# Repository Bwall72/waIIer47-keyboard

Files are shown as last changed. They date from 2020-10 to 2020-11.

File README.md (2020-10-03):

# WaIIer47 Mechanical Keyboard
Custom design 47 key ortholinear keyboard with PCB, and Atmega32u4 Microcontroller

## Images

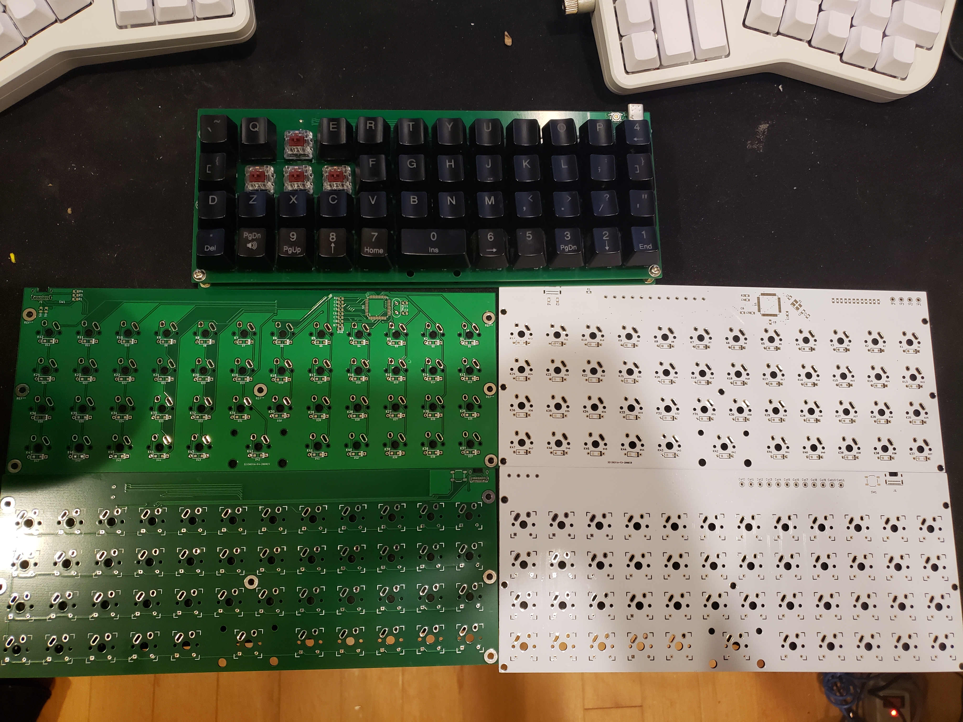
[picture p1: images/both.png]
Both Keyboards

Revision 2 Green, Revision 1 White, Back top, Front bottom

Revision 2
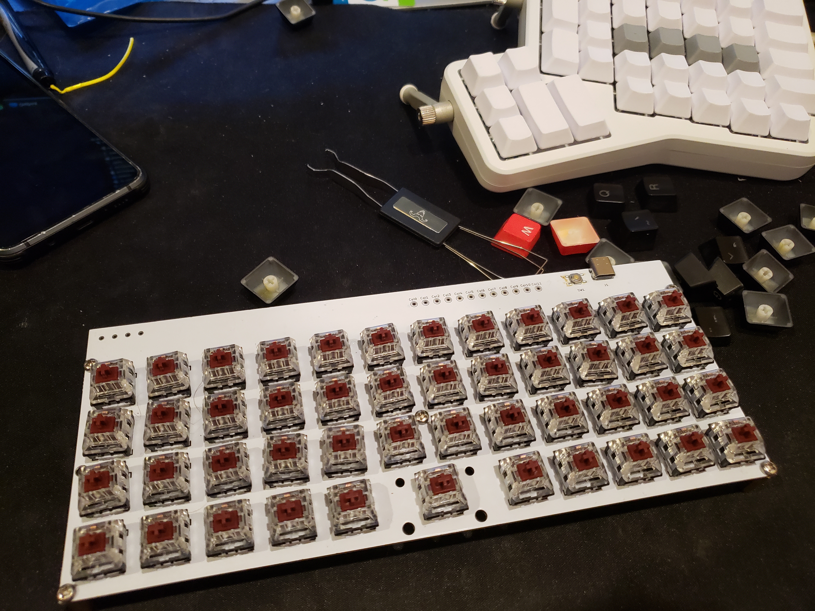
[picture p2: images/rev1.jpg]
Revision 1


# Bill Of Materials

* See [BOM.md](./BOM.md)
* The total cost for a Rev 2 PCB keybarod is:

| Component | Unit Price | Units | Total |
| --- | --- | ----- | ----- |
| Capacitor 22 pF | \$0.043  | 2 | \$0.086  |
| Capacitor 0.1 $\mu$F | \$0.0216  | 5 | \$0.108  |
| Capacitor 1.0 $\mu$F | \$0.055 | 1 | \$0.055 |
| Diode | \$.02446 | 47 | \$1.223 |
| LED | \$0.159 | 1 | \$0.159 |
| USB-C Receptacle | \$1.37 | 1 | \$1.37 |
| Kalih Speed Copper Key Switch | \$0.538 | 47 | \$25.286 |
| Resistor 10 k$\Omega$ | \$0.0071 | 2 | \$0.0142 |
| Resistor 22 $\Omega$ | \$0.0071 | 2 | \$0.0142 |
| Resistor 5.1 k$\Omega$ | \$0.0071 | 2 | \$0.0142 |
| Resistor 220 $\Omega$ | \$0.0071 | 1 | \$0.0071 |
| Push Button Switch | \$0.59 | 1 | \$0.59 |
| Atmega32U4 | \$4.08 | 1 | \$4.08 |
| Crystal Oscillator | \$0.36 | 1 | \$0.36 |
| PCB | \$2.08 | 2 | \$2.08 |
| M3 Screws | \$0.033 | 7 | \$0.233
| M3 Standoff | \$0.033 | 7 | \$0.233
| Total ||| \$35.89

>Notes
>
>* Shipping costs are excluded from the BOM
>* Currently, I am reusing keycaps, so those are not included in the BOM
>  * I am part of the group buy for [KAT Mizu Keycaps](https://old.reddit.com/r/mechmarket/comments/i6aaga/ic_kat_mizu_coming_september_1st/), which would add \$64.44 to the total
>* Kailh Speed Copper are my favorite switches, but they cannot be recomended for this keyboard. They are missing the pins to be used in a plateless keyboard like this one.

# PCB Tutorial
Designing a custom mechanical keyboard PCB using KiCad. The following was based on [Ruiqi Mao's Tutorial](https://github.com/ruiqimao/keyboard-pcb-guide)

## Download Kicad and Install the Mechanical Keyboard Libraries

* Download and install Kicad from https://kicad-pcb.org/
  * During installation, choose to download Kicad's default libraries
* Clone the following two repositories (or download zip and extract):
  * `keyboard_parts.pretty` from https://github.com/tmk/keyboard_parts.pretty
  * `keebs.pretty` from https://github.com/egladman/keebs.pretty
  * `Type-C.pretty` from https://github.com/ai03-2725/Type-C.pretty
  * `kicad_lib_tmk`.lib https://github.com/tmk/kicad_lib_tmk

  Kicad Libraries

* Open `Kicad` > `Preferences` > `Manage Footprint Libraries`
  * In the `Global Libraries` tab, press the folder icon to `Add existing library to table`
  * Navigate to where you cloned the the libraries, click on the `keebs.pretty` and press `OK`
    * Do the same for `keyboard_parts.pretty` and `Type-C.pretty`
  * If done successfully, you should see the following in the `Global Libraries` tab:

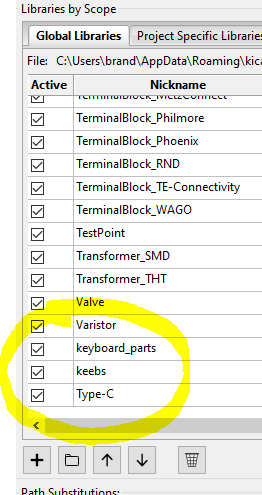
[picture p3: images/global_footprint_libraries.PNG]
Global Footprint Libraries
  
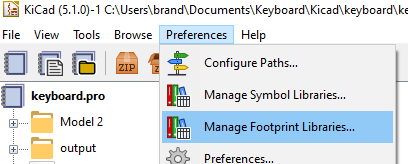
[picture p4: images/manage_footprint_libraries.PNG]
Manage Footprint Libraries
  

* Back in the Kicad Menu, `Preferences` > `Mange Symbol Libraries`
  * In the `Global Libraries` tab, press the folder icon to `Add existing library to table`
  * Navigate to where you cloned `kicad_lib_tmk` and select `keyboard_parts.lib`
  * Navigate to `Type-C.pretty` and select `Type-C.lib`
  * If done successfully, you should see the following:

  Global Symbol Libraries

## Creating The Schematic File

* In Kicad: `file` > `New` > `New Project`
  * Create a new Folder for the project, and give a name for the project (I am using `tutorial_keyboard`)
  * Press `Save`
  * On the left side, you should now see 3 files:
    * `tutorial_keyboard.kicad_pcb`: The PCB file
    * `tutorial_keyboard.pro`: The project file, we will not be using this
    * `tutorial_keyboard.sch`: The schematic file

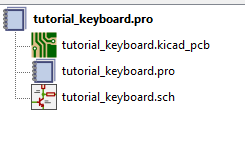
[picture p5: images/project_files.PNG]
Project Files
  

* Click on the `Schematic Layout Editor` button
* Because this schematic will be large, increase the paper size by going to `file` > `Page Settings...` then selecting the `C` page size

## Placing Components on the Schematic

* To place a part, press the `Place symbol` button on the right side
* For the microcontroller:
  * `Place symbol` and click on the page > expand `keybord_parts` > select `ATMEGA32U4` > press `OK` > Click on the sheet to place the component
  * You should now see the component placed on your page with the label U?
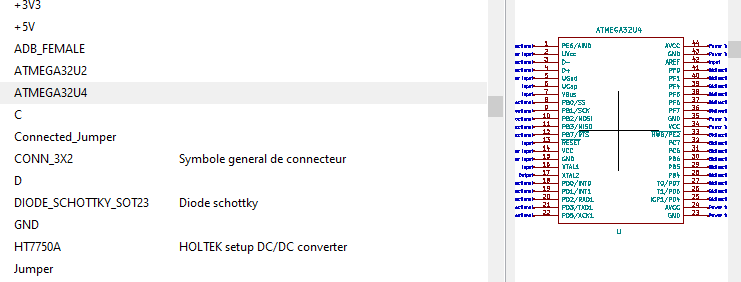
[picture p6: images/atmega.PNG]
Atmega Symbol
  
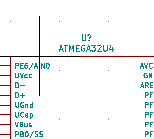
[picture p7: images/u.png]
U?
  
* Place the following components as required by the [datasheet](http://ww1.microchip.com/downloads/en/devicedoc/atmel-7766-8-bit-avr-atmega16u4-32u4_datasheet.pdf)
  * A 10 k$\Omega$ resustor near `HWB/PE2`
    * `Place symbol` > `keyboard_parts` > `R` > `Ok`
      * Press `r` before placing the component, or while hovering over the component after placing to rotate it
      * Hover over it and press `e` to `Edit Value Field`
      * Change the `Text` field to say `10k`
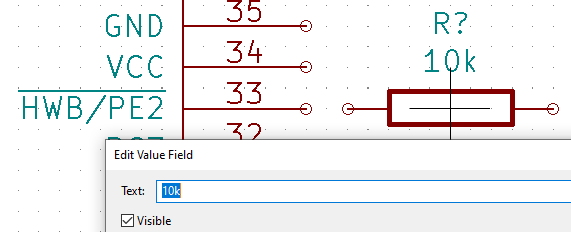
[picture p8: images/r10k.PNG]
R10k
    
  * A 1 $\mu$F capacitor on `UCap`
    * `place symbol` > `keyboard_parts` > `C` > `Ok`
    * Change the its value to `1uF`
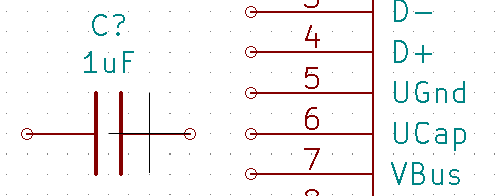
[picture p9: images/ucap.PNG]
UCap
    
    UCap datasheet
* Connect `Vcc` and `GND`
  * On the right side, slect `Place power port` > click on the page
  * Expand the `power` library and select > `VCC` > `Ok`
  * Place the VCC flag near `AVCC`
    * On the right, click the `Place wire` icon
    * Click at the empty circle on `AVCC` and make a connection to the `VCC` flag
    AVCC Connection
    * Repeat for:
      | Pin | Name   |
      |-----|--------|
      | 2   | `UVcc` |
      | 7   | `VBus` |
      | 14  | `VCC`  |
      | 24  | `AVcc` |
      | 34  | `VCC`  |
      | 44  | `AVcc` |
    * Make sure there are 6 total connections to `VCC`
    * Individual connections to `VCC` in the schematic do not need to be connected together
    * Connect `VCC` to a power flag
      * `Place symbol` > Search for `PWR_FLAG` > `PWR_FLAG`
      * Connect the `PWR_FLAG` to `VCC`
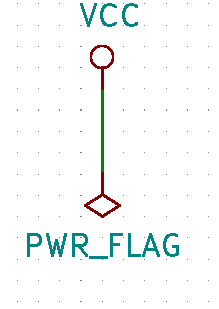
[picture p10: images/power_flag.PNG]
Power Flag
      
  * `Place power port` > `GND` (`Power flag, ground` from the `s`power` library)
    * Create a connection to `GND` on the following pins:
      | Pin | Name   |
      | --- | ------ |
      | 5   | `UGND` |
      | 15  | `GND`  |
      | 23  | `GND`  |
      | 35  | `GND`  |
      | 43  | `GND`  |
    * Additionally, connect the other end of the capacitor and resistor to `GND`
    * Make sure there are 5 connections to `GND`
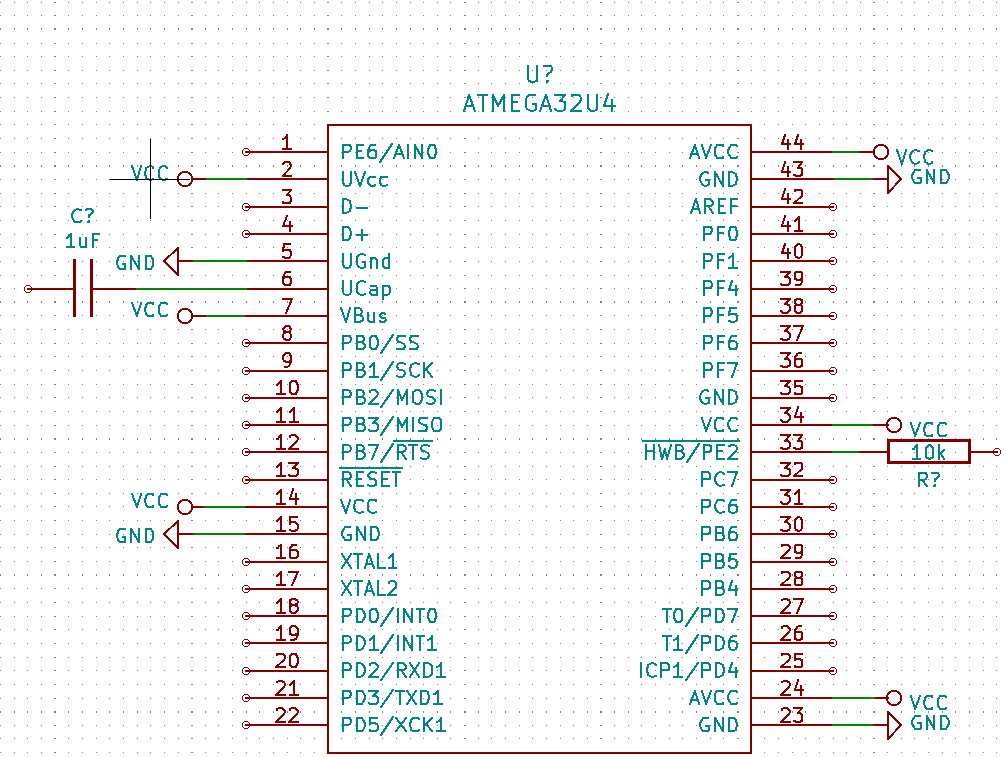
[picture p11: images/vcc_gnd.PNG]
VCC and Ground on uc
    

* If there are any overlapping components or labels, press `m` over the component/label to move it somewhere else
  * You will have to remake any connections
* Reset Circuit
  * The following allows for a manual reset button that (If you do not want a reset button, connect `RESET` to `VCC`)
  * Move to an open part of the page
  * `Place symbol` > `keyboard_parts` > `SW_PUSH`
  * We want the voltage supplied to the reset pin to be `High (5V)` normally, and ground when pushed to reset the microcontroller
  * Connect the left side to `GND`
  * Create a connection between `VCC` -> 10 k$\Omega$ resistor -> switch-s right pin
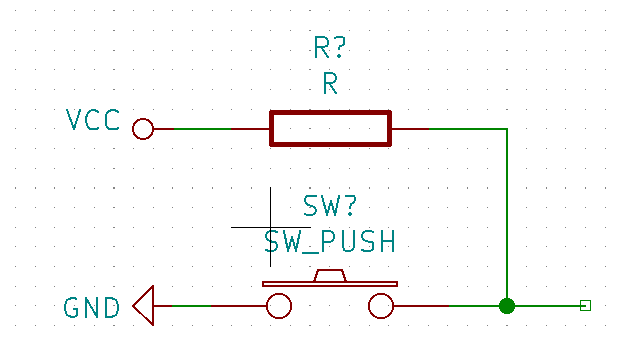
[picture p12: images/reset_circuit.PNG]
Reset Circuit
  
  * Place a flag on the right side:
    * In the right menu: `Place net label`
    * Give it the name `Reset`
    * Connect it to the wire on the right side
    * Place a net label with the name `Reset` on the `RESET` pin (pin 13) of the microcontroller
    * The reset circuit is now connected to the microcontroller
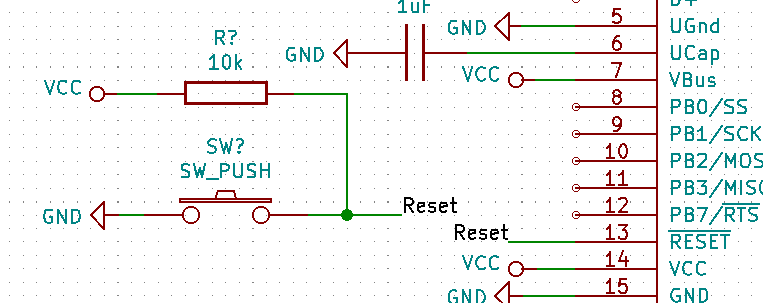
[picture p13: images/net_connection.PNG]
Reset net connection
    
* USB Type-C Circuit
  * This keyboard will connect to a computer using a USB-C connector in USB 2.0 Mode
  * `Place symbol` > `Connector` > `USB_C_Receptacle_USB2.0`
  * Make the following connections

  | Receptacle Port | Connection |
  | --------------- | ---------- |
  | `VBUS` | `VCC` |
  | `CC1` | 5.1 k$\Omega$ resistor -> `GND` |
  | `CC2` | 5.1 k$\Omega$ resistor -> `GND` |
  | `D-` | Connect both `D-` pins through a 22 $\Omega$  resistor to a net called `D-` |
  | `D+` | Connect both `D+` pins through a 22 $\Omega$ resistor to a net called `D+` |
  | `SBU1` | Leave unconnected |
  | `SBU2` | Leave unconnected |
  | `GND` | `GND` |
  | `SHIELD` | `GND` |
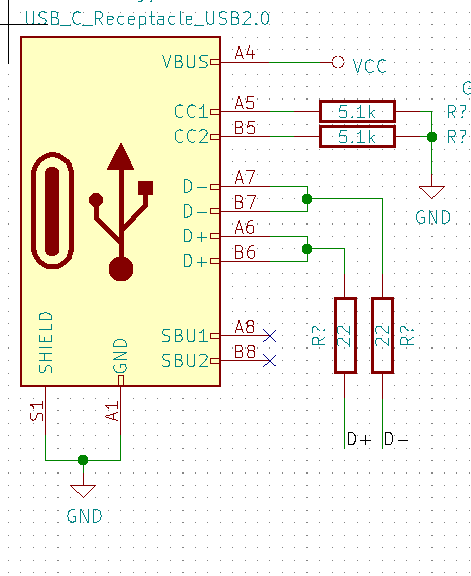
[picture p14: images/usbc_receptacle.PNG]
USB-C Receptacle
  
  * On the microcontroller, connect `D-` (pin 3) to the `D-` net and `D+` (pin 4) to the `D+` net
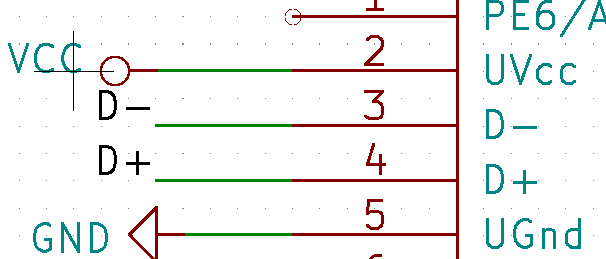
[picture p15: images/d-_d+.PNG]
D- and D+ connections
  

* Crystal Oscillator Circuit
  * The following circuit is required for the microcontroller to function as a USB device
  * `Place symbol` > `keyboard_parts` > `XTAL`
  * Connect a 22 pF capacitor to both ends of the `XTAL` with the other side going off to `GND`
  * Connect one side of the `XTAL` to a net called `xtal1` and the other to a net called `xtal2`
  * Connect the `xtal1` net to `XTAL1` (pin 16) and `xtal2` to `XTAL2` (pin 17) on the microcontroller
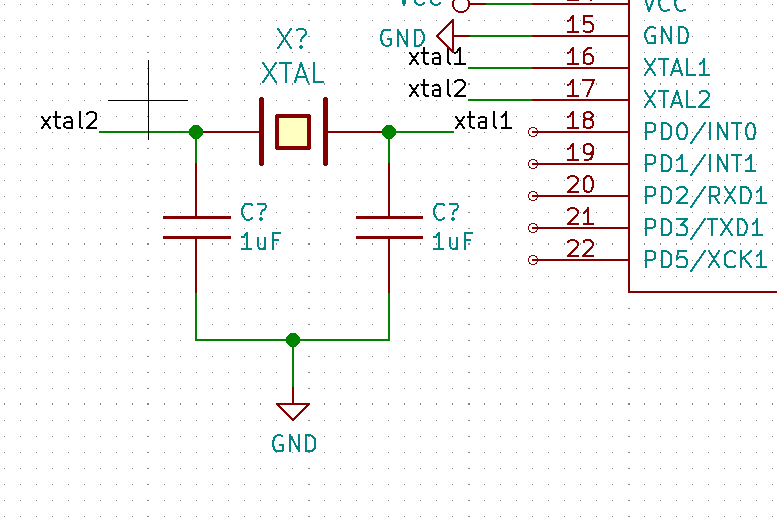
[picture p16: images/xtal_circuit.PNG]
Crystal Circuit
  

* Placing the keys
  * The following circuit is used for all the keys:
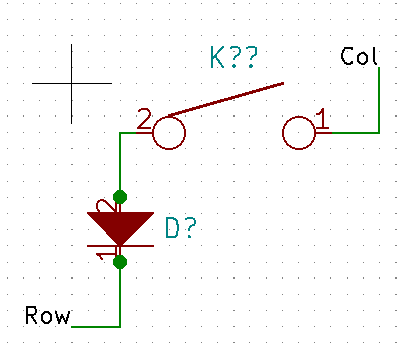
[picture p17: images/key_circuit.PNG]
Key circuit
  
  * `Place symbol` > `keyboard_parts` > `KEYSW`
  * `Place symbol` > `keyboard_parts` > `D`
  * Connect the `2 pin` on the `KEYSW` on to the 2 pin on the diode **Orientation on the diode is extremely important**
  * For an 47 key ortholinear keyboard, copy and paste this circuit 46 times in rows of 12 (besides the third row which should have 11 keys)
  * Connect all the pin 1's on the switch on the same row
  * Connect all the pin 1's on the diode to the next pin 2 on the switch in the columns
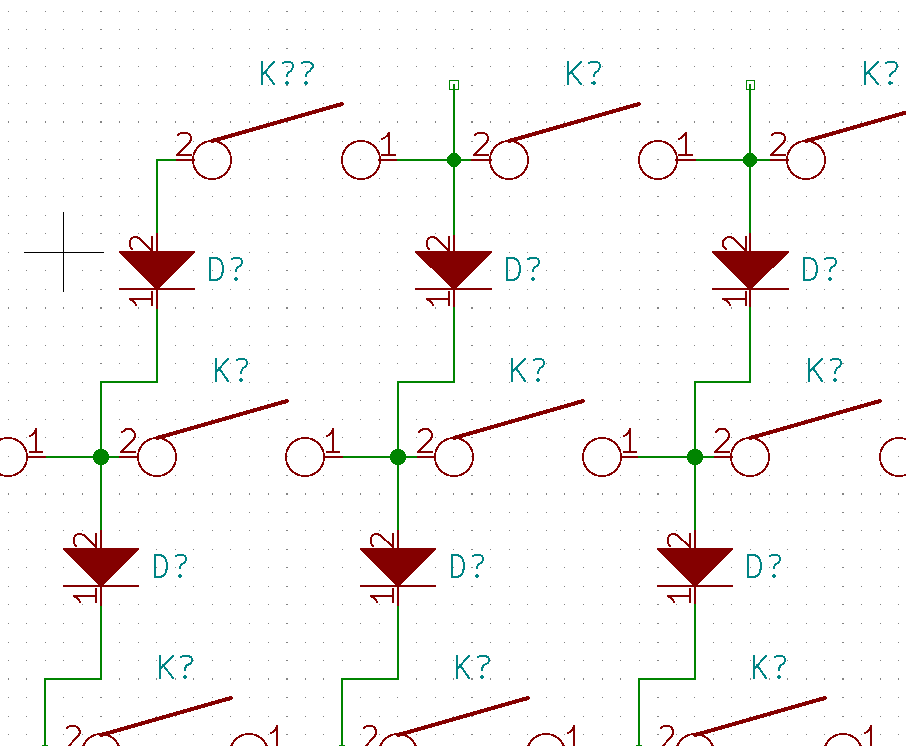
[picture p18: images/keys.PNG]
Keys
  
  * Connect the bottom row diodes together
  Row 3
  * Create a net on the each of the vertical wire segments in the top row named `col0` to `col11`
  * Create a net on the the left most switch of each row labeled `row0` to `row3`
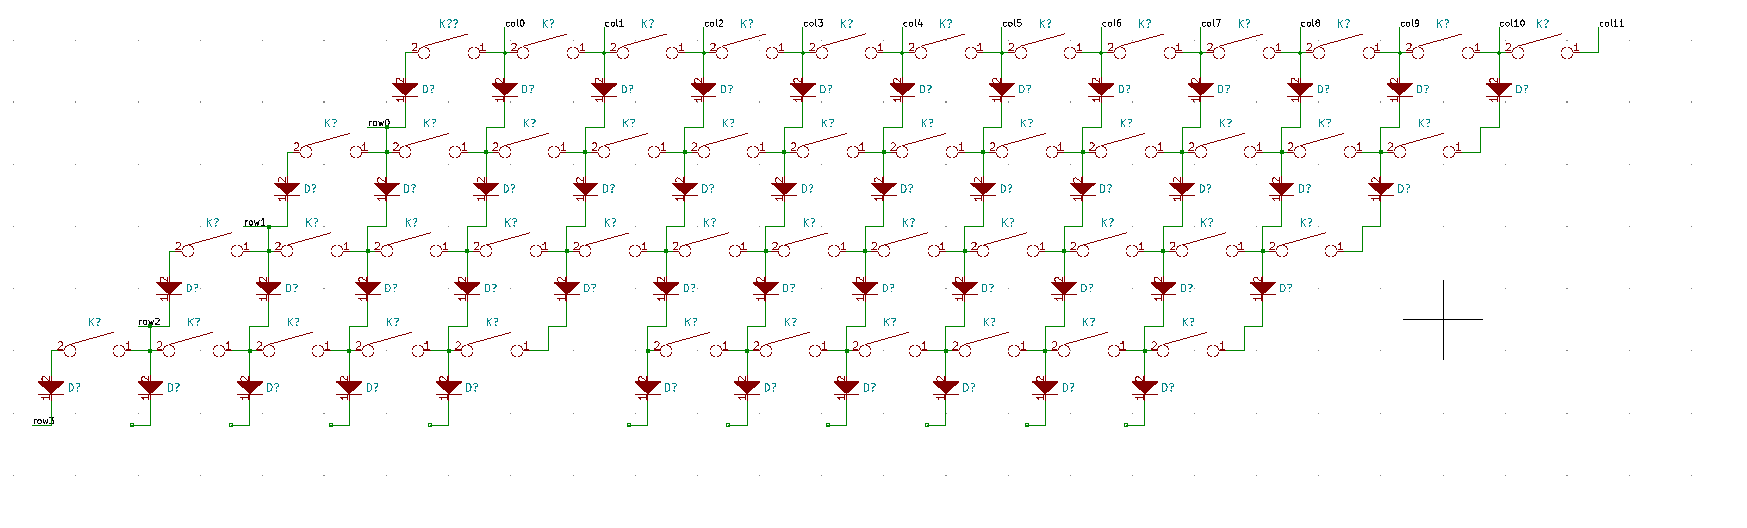
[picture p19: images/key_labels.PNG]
Key labels
  
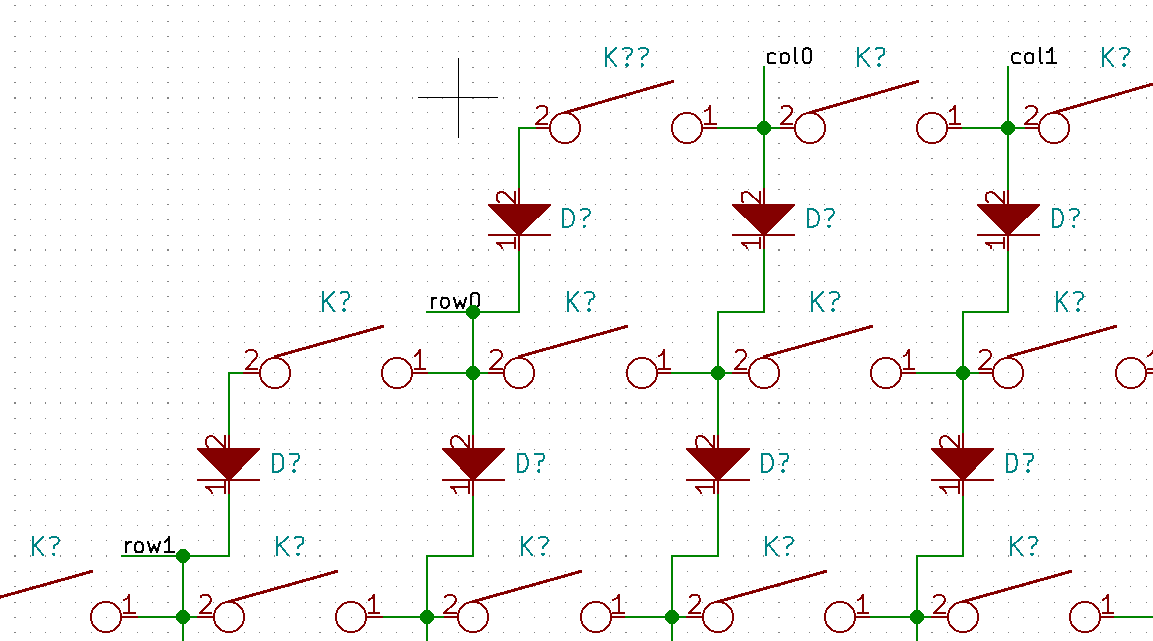
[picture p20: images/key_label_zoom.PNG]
Key label zoom
  
  * Connect each of the row and col nets to a GPIO pin on the microcontroller (`PAX`, `PBX`, `PCX`, or `PDX`) these can be changed later to make it easier to route the PCB
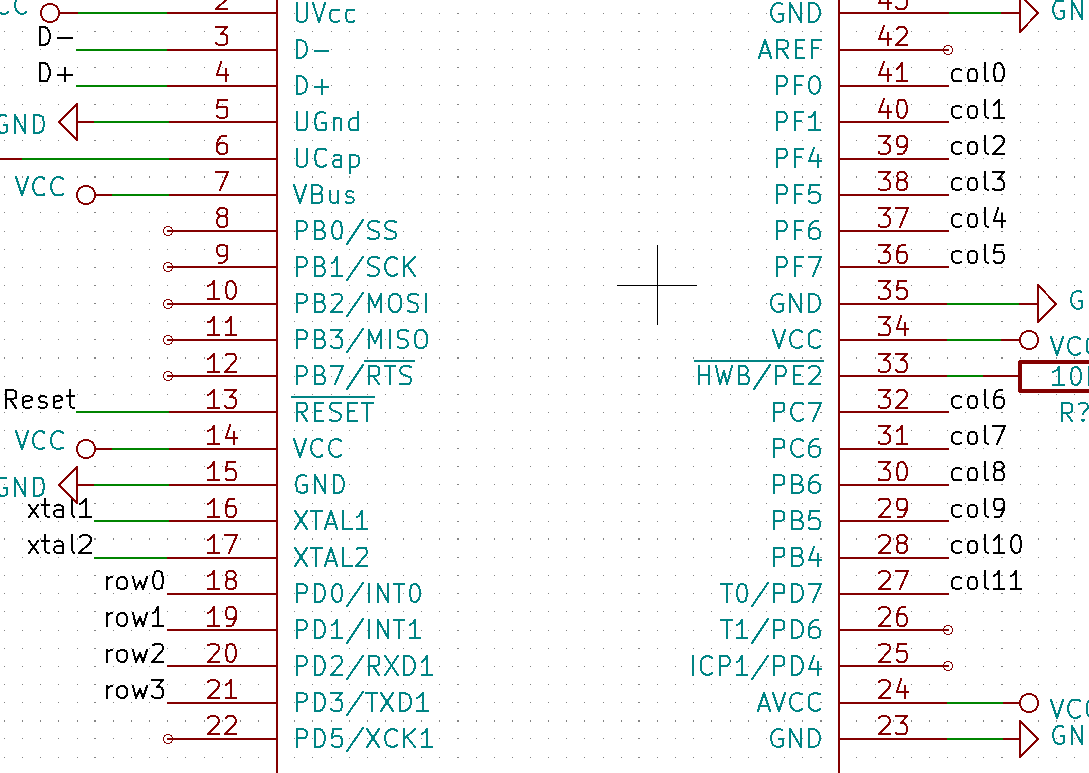
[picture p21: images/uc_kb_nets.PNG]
Microcontroller keyboard nets
  
* Bypass Capacitors
  * Bypass capacitors are placed between all `VCC` nets and `GND`, watch this [video to learn more](https://www.youtube.com/watch?v=BcJ6UdDx1vg)
  * There are 6 connections that will use bypass capacitors
  * Create the following circuit using 0.1 $\mu$ capacitors
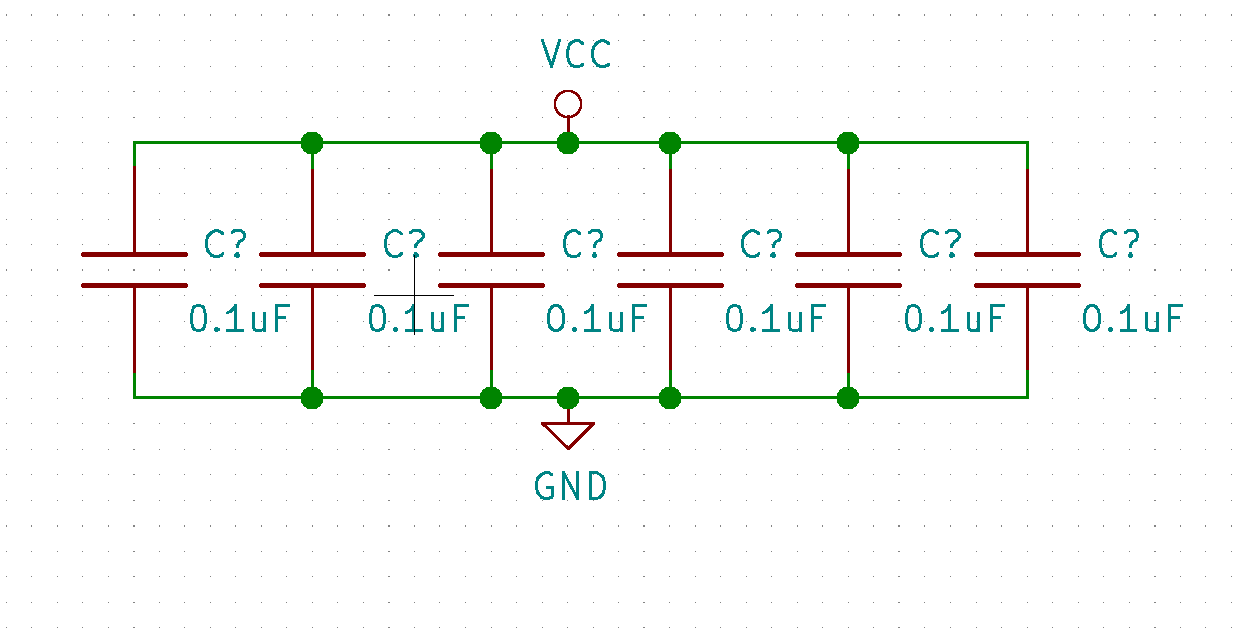
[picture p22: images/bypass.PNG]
Bypass capacitor circuit
  
* Mark all unconnected ports
  * In the right menu, click `Place no connection flag`
  * Place the symbol over all unused ports on the microcontroller and on `SBU1` and `SBU2` on the USB C receptacle
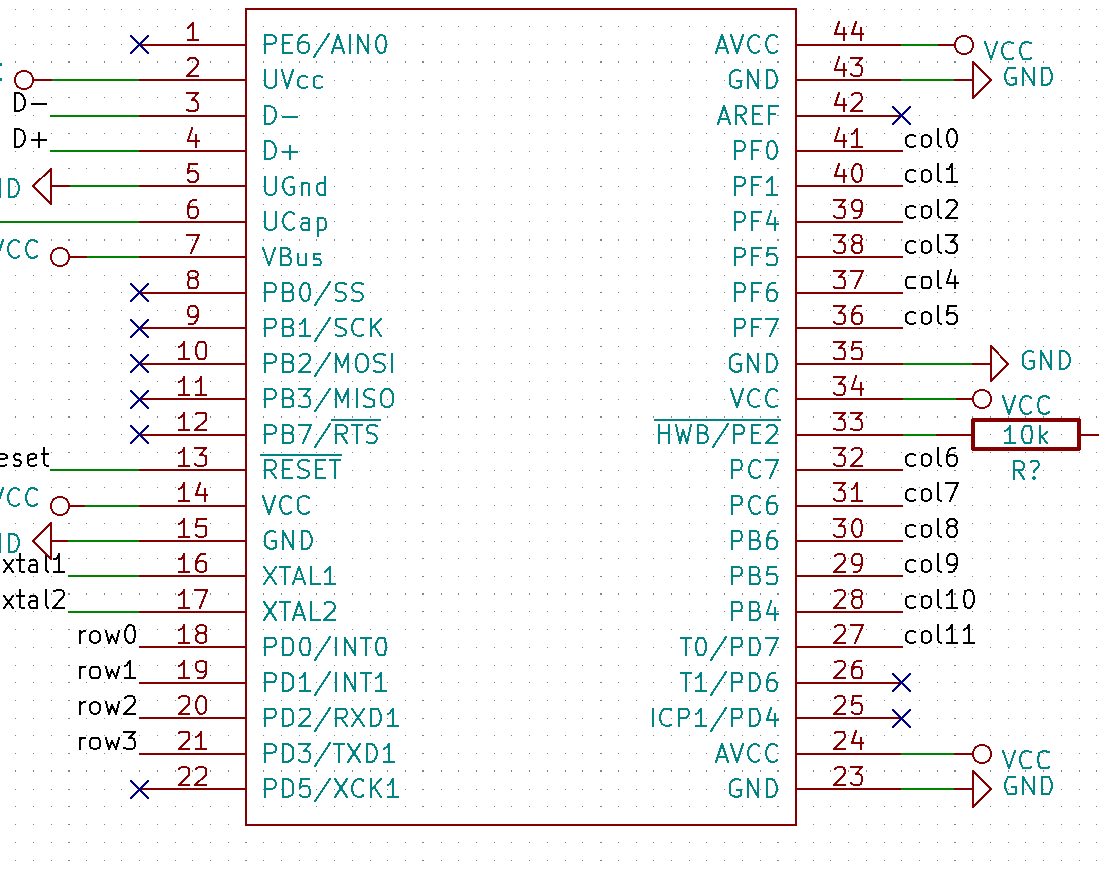
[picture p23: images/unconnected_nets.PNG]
Unconnected nets
  
* Annotate the schematic to give components names
  * `Tools` > `Annotate Schematic`
  * Keep all default settings
  * Press `Annotate`
  * `Close`
* Run a Design Rules Check to make sure there are no errors in the circuit
  * `Perform electrical rules check` > `Run`
  * Fix any errors that occur, if there are only errors for your `VCC` or `GND` not being driven, you can move on
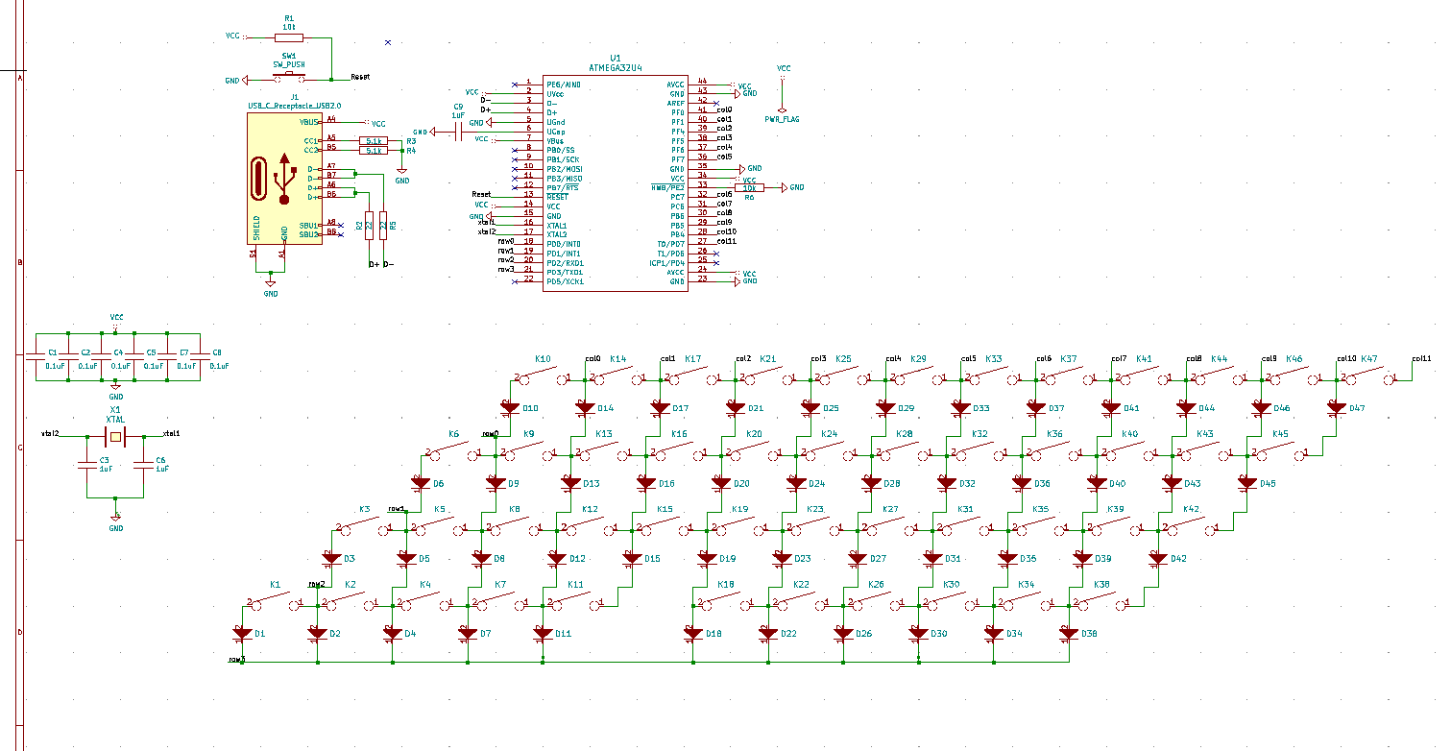
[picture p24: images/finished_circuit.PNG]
Finished Circuit


## Assigning Footprints

* Assigning footprints tell the PCB software what size to make all of your components. Additionally you will buy components based off the size of their footprint. For most components we will use the `0805` surface mount package. If you do not feel comfortable surface mounting components, you will have to heavily modify the PCB layout.
* `Tools` > `Assign Footprints...`
  | Components | Library | Footprint |
  | ---------- | ------- | --------- |
  | All Capacitors | `Capacitor_SMD` | `Capacitor_SMD:C_0805_2012Metric` |
  | All Diodes | `Diode_SMD` | `Diode_SMD:D_0805_2012Metric` |
  | USB C Receptacle | `Type-C` | `Type-C:USB_C_GCT_USB4085` |
  | All `KEYSW` **EXCEPT FOR THE SPACE BAR** | `keebs` | `keebs:Mx_Alps_100` |
  | Space Bar (sixth key in on the bottom row) | `keebs` | `keebs:Mx_Alps_200` |
  | All Resistors | `Resistor_SMD` | `Resistor_SMD:R_0805_2012Metric` |
  | `SW_PUSH` | `Button_Switch_SMD` | `Button_Switch_SMD:SW_SPST_TL3342` |
  | `ATMEGA32U4` | `Package_QFP` | `Package_QFP:TQFP-44_10x10mm_P0.8mm` |
  | `XTAL` | `keyboard_parts` | `keyboard_parts:XTAL_HC_49_TH`
    Footprint 1
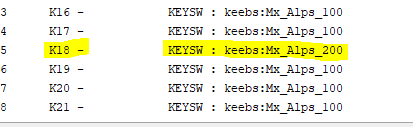
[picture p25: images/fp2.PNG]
Footprint 2
    
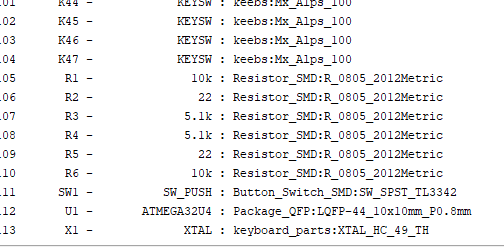
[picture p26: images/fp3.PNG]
Footprint 3
    
  * Press `OK`

## Creating the PCB

### Set the Grid Size

* Click the `Grid` dropdown menu on the top
* `Edit User Grid`
* Set `Size X` and `Size Y` to `0.254`

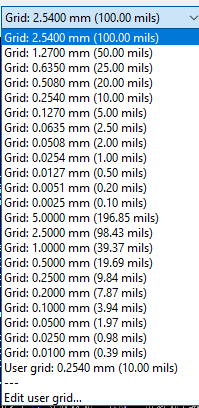
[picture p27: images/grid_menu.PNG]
Grid Menu

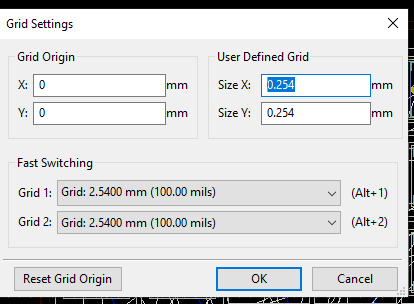
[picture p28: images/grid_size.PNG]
Grid Size


### Importing From the Schematic

* Close the schematic and open `PCB Layout Editor`
* `Tools` > `Update PCB from Schematic`
* Click Anywhere to Place all the components
* Click `Layers Manager` > `Items` > Uncheck the box next to `Ratsnest`
  * This will be helpful when routing the PCB, but it is not now

### Organizing your components

* Arrange the keys in the same order as your circuit
* The easiest way I found to do this is to use `ctrl + f` to search for the key annotations
* I like to leave one _grid snap_ gap between each key, make sure all keys are evenly spaced on the grid
* There should be a visible `+` sign between all groups for 4 adjacent keys

> Follow the annotations from your schematic to put the keys in the correct order

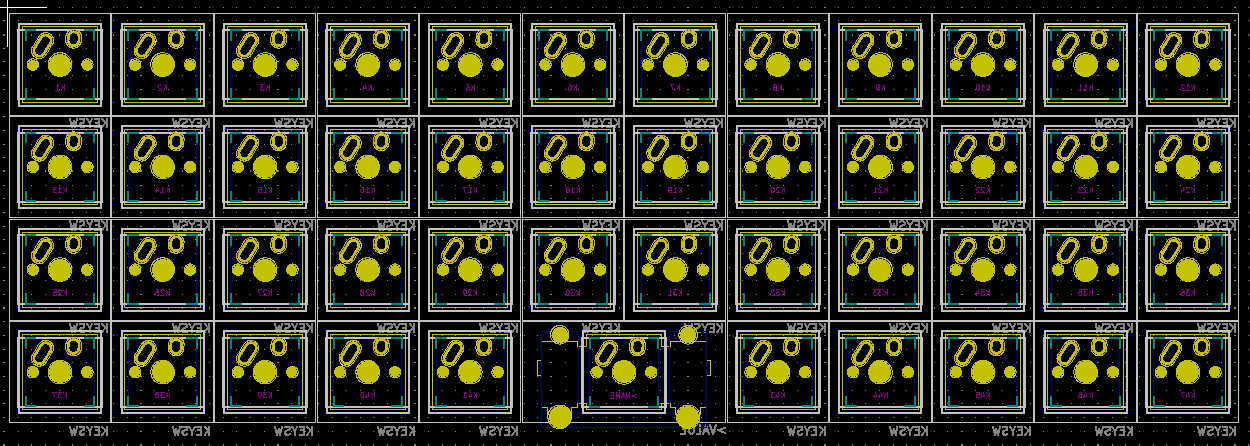
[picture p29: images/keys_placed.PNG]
Keys placed

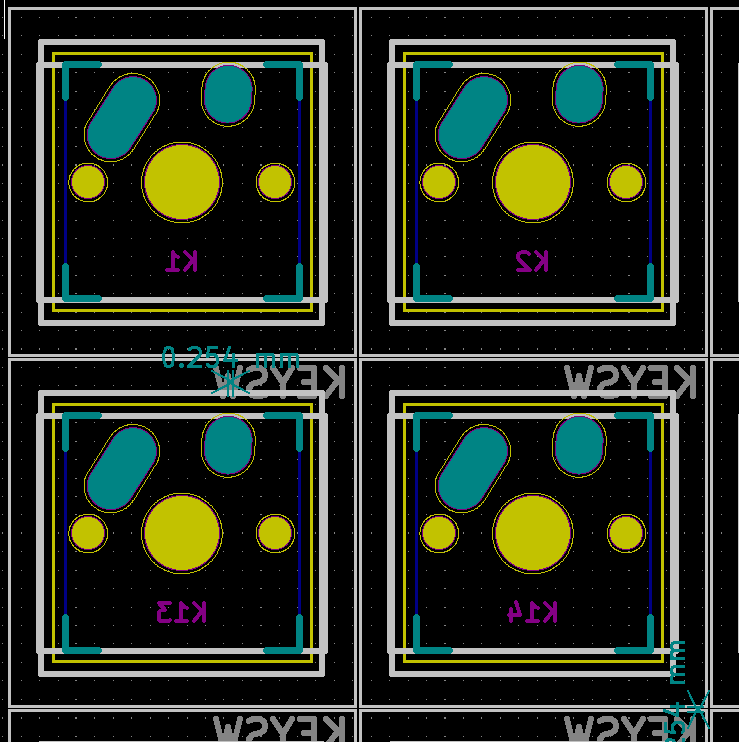
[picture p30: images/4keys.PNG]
Zoom in


### Place the Other Parts

* Because this keyboard mostly uses surface mount components, they will mostly go on the back to hide them
* To place a component on the back, click on the footprint and press `f`
  * The text for the label should be backwards and in purple
* Flip all diodes to the back, and align them onto their key switch
* Place the diode on the lower part of the key switch (opposite of the gold)

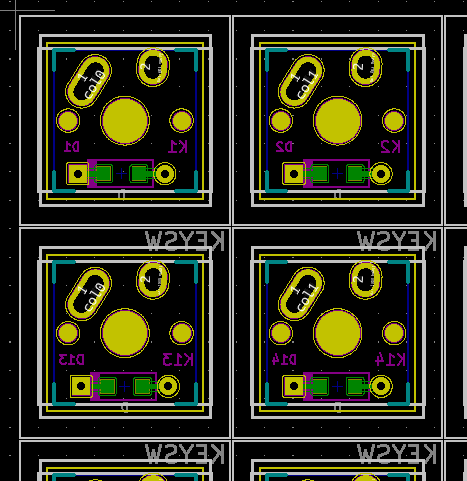
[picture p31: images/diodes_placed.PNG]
Diodes placed


* Turning on `ratsnest` may be helpful for this part
* Arrange the other parts on the back above the key switches
  * All the components in the schematic that are near the microcontroller should go near the microcontroller
  * 5 bypass capacitors should go near the microcontroller with the other going near the USB-C receptacle
* The crystal should go on the back as close as possible to the microcontroller pins it connects to
* The Type-C connector should go on the front, it will be the highest component on the PCB
* The switch can go on the front or back based on preference, I put it on the front

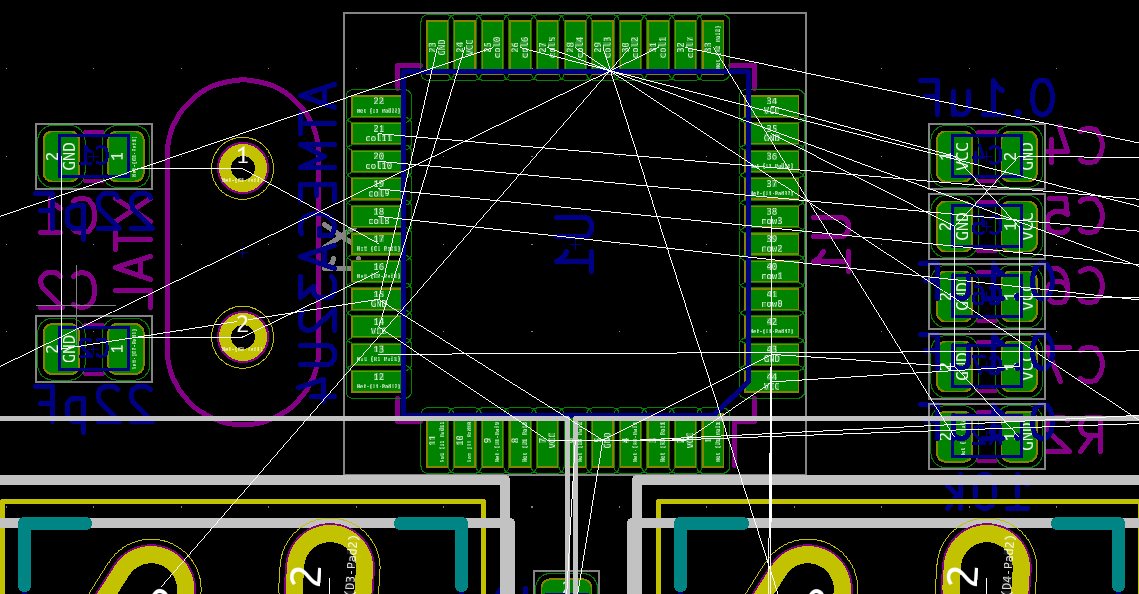
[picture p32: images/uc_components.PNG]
Microcontroller circuit

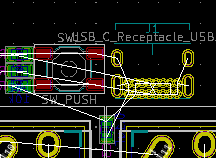
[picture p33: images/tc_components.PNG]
Type-C circuit


### Adjust your circuit

* With the `ratsnest` turned on, move the location of rows and cols on your microcontroller to reduce the number of ratsnests that overlap
* After making a change, `Tools` > `Update PCB From Schematic`

### Set the Track Width

* I use [JLCPCB](https://jlcpcb.com/) to manufacture my PCBs, their minimum trace width is 5 mil (0.127 mm) with the same minimum spacing

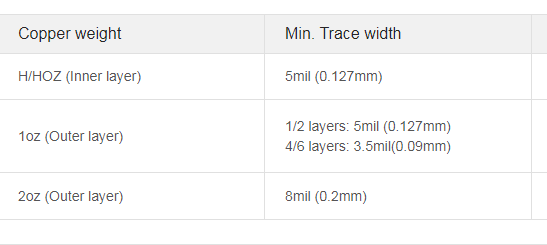
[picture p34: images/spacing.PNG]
JLCPCB min spacing


* The default .254 mm width does not need to be changed, but you can go down to .2 mm to have smaller traces

### Making connections

* To make a connection, use the bar on the right to select a layer
  * `F.CU` for components on the front
  * `B.CU` for components on the back
* You must select the layer of the starting component to make a connection
* With the correct layer selected, press `Route tracks`
* Connect all components, but do not connect any `GND` nets, those will all be taken care of in the end

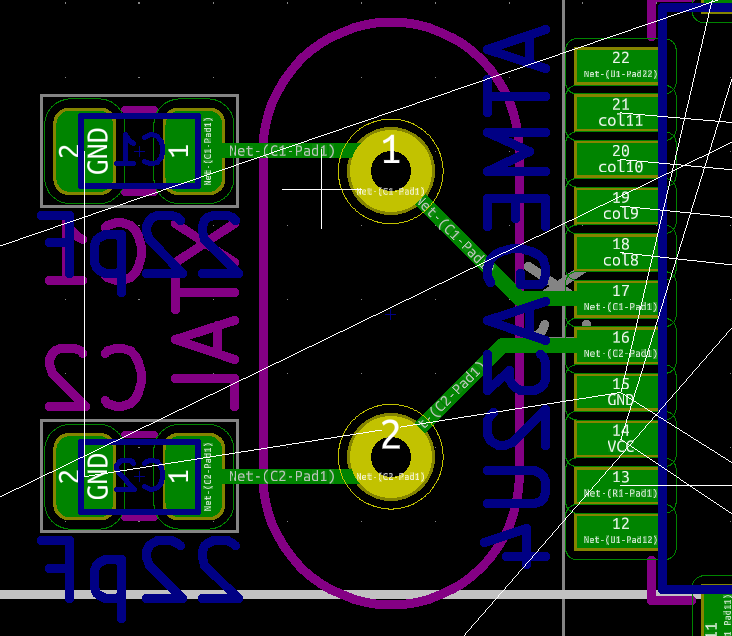
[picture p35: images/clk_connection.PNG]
Clock connection


* To make connections easier, click on the footprint and press `R` to rotate the component if that makes it easier
* I recommend breaking out all the pins of the microcontroller before worrying about connecting the microcontroller to components
* If traces are going to overlap, press `v` to insert a `via` between the front and the back to switch layers

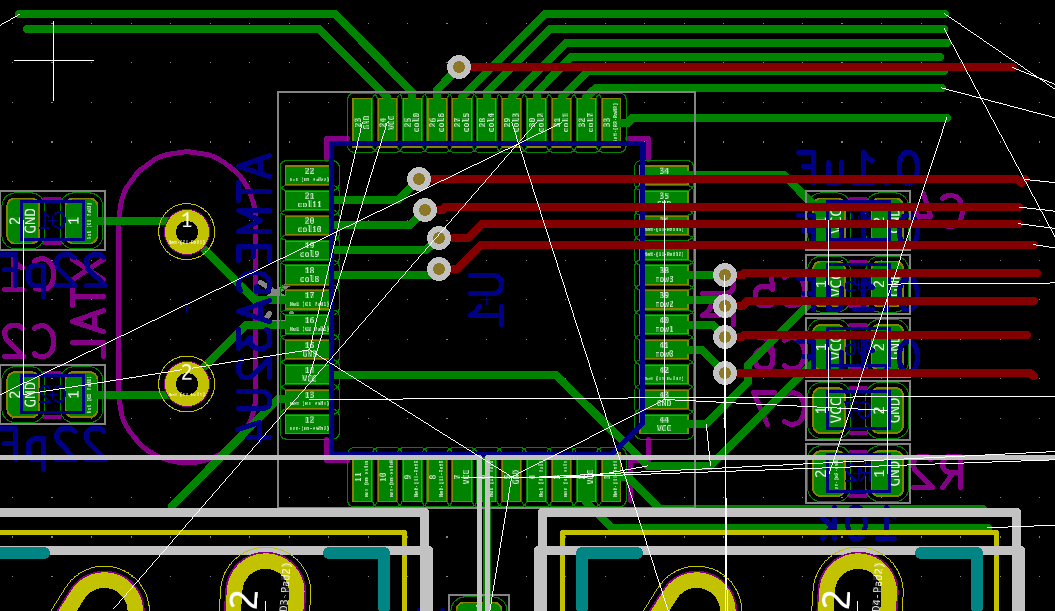
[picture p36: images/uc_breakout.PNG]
Microcontroller breakout


### Create the Remaining Connections

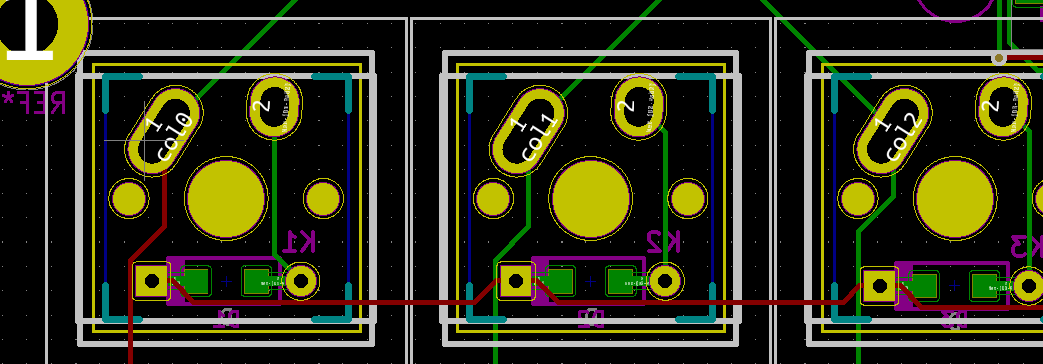
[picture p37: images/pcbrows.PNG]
PCB Row Connections


Connect the diodes for all keys in the same row

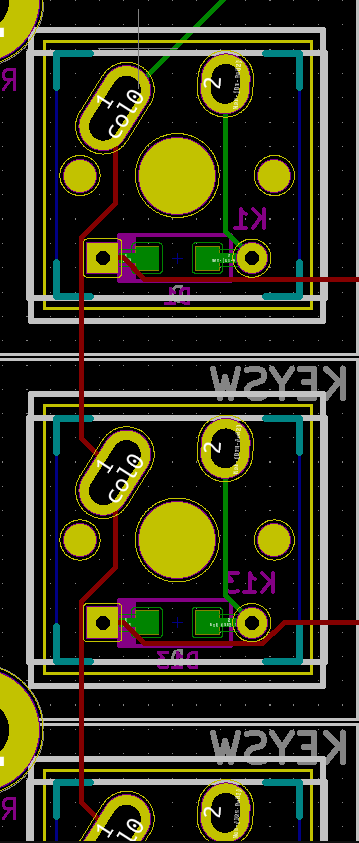
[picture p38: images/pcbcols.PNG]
PCB Col Connections


Connect the switches in the same column

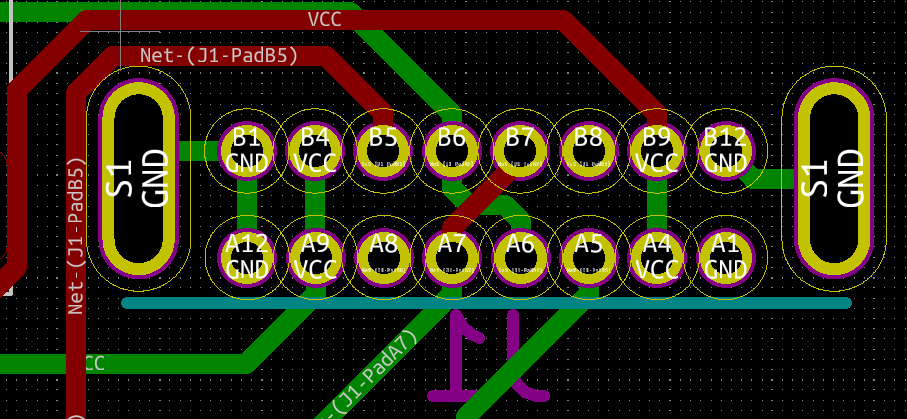
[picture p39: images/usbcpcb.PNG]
USB Receptacle Connections


Break out connections from the USB-C receptacle

### Add Mounting Holes

* This desing suspends the PCB from standoffs, to use them, m3 screw holes are added to the PCB
* `Place` > `Footprint` > `MountingHole_3.2mm_M3`
* I personally put 3 screw holes on each side and one in the middle
  * Adding more holes can make the PCB flex less

Mounting Holes

### Creating an outline for the PCB

* Select the `Edge.Cuts` layer
* Select the `Add graphic lines` tool
* Draw a **fully connected** rectangle around all your components
* The USB-C connector should be on the outer limits of the PCB on the top, and the screw holes should be the limit on the sides
* The smaller the PCB, the cheeper it will be to fabricate

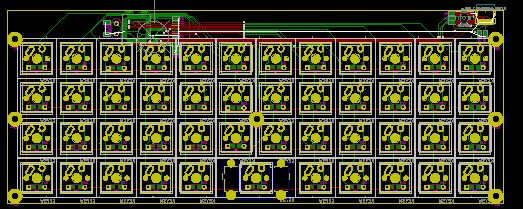
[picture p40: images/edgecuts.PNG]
Edge Cuts


* After creating the outline, try opening `View` > `3D Viewer`
* If you see the folowing error, look for any missing connections in your edge cuts or extra lines

Edge Cut Error

* Once you fix all the errors, you should be able to view a 3D rendering of the PCB

3D View

### Adding a Ground Plane

* In the previous steps, no connections were made to ground, we will resolve them all now
* On the right side, select the `Add filled zones` tool on the back side and the `GND` net

Filled zone settings

* Select the top left corner > top right corner > bottom right corner > **double click on the lower left corner**
* You should see:

Bottom filled zone

* By zooming in, you can see connections made to ground nets

Bottom filled zone zoom in

* Repeat the process on the top side

Top zone

> Press the `Do not show filled zones` button on the left side to hide the filled zones

### Run the Design Rules Check

* Press `Perform Design Rules Check` on the top bar
* Select the `Refill all zones before running DRC` > `Run DRC`
* Resolve any errors that show up
* The most common errors are:
  * Missing connections to ground:
    * It is possible that your filled zones cannot get around a trace or component, you may need to add some manual ground connections
  * Traces too close:
    * Re-route the traces to increase the distance between the traces
  * Traces too close to holes in PCB
    * Move the trace
* When there are no design rule check violations, the PCB is complete

Design rules check

## Submitting PCB for Fabrication

### Generate Gerber Files

* [Refer to this page from JLCPCB for instructions](https://support.jlcpcb.com/article/44-how-to-export-kicad-pcb-to-gerber-files)
* `File` > `Plot`
* Select a folder for `Output Directory`
* On the front page, leave all the default settings and press `Plot`
* Press `Generate Drill Files...`
  * Click the `Gerber` option on the left
  * Press `Generate Drill File`

Plot
Drill

### Submitting to JLCPCB
(Instructions will also be shown for [OSHPARK](https://oshpark.com/), but they are much more expensive for large PCBs)

* Create a `.zip` from the output folder
* Go to [JLCPCB](www.jlcpcb.com)
* Press `QUOTE NOW`
* `Add your gerber file` > Select your `.zip`
* You can leave all the default options unless you want a different color
* Proceeded with checkout, they will verify your that your design complies with their manufacturing process and has all the needed files
* \$10.40 + 16 for Fedex Shipping
* Total time to receive your PCB should be less than two weeks (unless shipping by boat)

JLCPCB gerber upload

JLCPCB Quote

### OSHPARK

* PCBs from OSHPARK are more expensive, but higher quality. For large runs, it may make sense to use OSHPARK (you also have to be fine with a purple PCB)
* Go to [wwww.oshpark.com](www.oshpark.com)
* Upload your `.zip`
* I saw that their quote was 5 times as much for 2 fiewer PCBs and did not continue...

OSHPARK Quote

# Ordering Components from Digikey

* For this tutorial, the following components are purchased from [Digikey](www.digikey.com)
* Note the quantities needed per the schematic and **BUY MORE THAN YOU NEED**, **A LOT MORE** (I generally buy 5-10 times as many of each component, it is often cheaper to buy at higher quantities)

| Item # | Item | Price | Digikey Link | Data Sheet |
| --- | ---- | ---| ---| --- |
1 | USB C Connector | \$1.37 | [Link](https://www.digikey.com/product-detail/en/gct/USB4085-GF-A/2073-USB4085-GF-ACT-ND/9859733) | [Link](https://media.digikey.com/pdf/Data%20Sheets/GCT%20PDFs/Ionex_USB_Conn_Br.pdf)
2 | Capacitor (22pF) | \$0.043 | [Link](https://www.digikey.com/product-detail/en/w%C3%BCrth-elektronik/885012007012/732-7816-1-ND/5454443) | [Link](https://www.we-online.de/katalog/datasheet/885012007012.pdf)
3 | Capacitor (0.1 $\mu$F) | \$0.0216 | [Link](https://www.digikey.com/product-detail/en/samsung-electro-mechanics/CL21B104KACNNNC/1276-1099-1-ND/3889185) | [Link](https://media.digikey.com/pdf/Data%20Sheets/Samsung%20PDFs/CL21B104KACNNNC_Spec.pdf)
4 | Capacitor (1 $\mu$F) | \$0.055 | [Link](https://www.digikey.com/product-detail/en/samsung-electro-mechanics/CL21B105KOFNNNE/1276-1026-1-ND/3889112) | [Link](https://www.datasheets360.com/pdf/5320303544541785574)
5 | Diode | \$.02446 | [Link](https://www.digikey.com/product-detail/en/nexperia-usa-inc/BAS16GWJ/1727-7320-1-ND/7390571) | [Link](https://assets.nexperia.com/documents/data-sheet/BAS16GW.pdf)
6 | Resistor (10 k$\Omega$) | $0.0071 | [Link](https://www.digikey.com/product-detail/en/stackpole-electronics-inc/RMCF0805JT10K0/RMCF0805JT10K0CT-ND/1942577) | [Link](https://www.seielect.com/catalog/sei-rmcf_rmcp.pdf)
7 | Resistor (22 $\Omega$) | $0.0071 | [Link](https://www.digikey.com/product-detail/en/stackpole-electronics-inc/RMCF0805JT22R0/RMCF0805JT22R0CT-ND/1942533) | [Link](https://www.seielect.com/catalog/sei-rmcf_rmcp.pdf)
8 | Resistor (5.1 k$\Omega$) | $0.0071 | [Link](https://www.digikey.com/product-detail/en/stackpole-electronics-inc/RMCF0805JT5K10/RMCF0805JT5K10CT-ND/1942571) | [Link](https://www.seielect.com/catalog/sei-rmcf_rmcp.pdf)
9 | Switch | $0.59 | [Link](https://www.digikey.com/product-detail/en/e-switch/TL3342F160QG-TR/EG2531CT-ND/379004) | [Link](https://sten-eswitch-13110800-production.s3.amazonaws.com/system/asset/product_line/data_sheet/165/TL3342.pdf)

* To search on your own for components (resistor example):
  * Go to [Digikey](https://www.digikey.com/)
  * `Products` > `Passives` > `Resistors` > `Chip Resistor - Surface Mount`
  * Use the filters to get the correct value resistor
  * Set the `View Prices At` value to 10
    * For most components, I ended up in the 10-100 piece price bracket
    * This will exclude any components that can only be purchased in high quantities
    * Click `More Filters`
    * `Package` > `0805` (based on the assigned footprint)
    * `Apply All`
    * I also recommend deselecting `Include` under `Marketplace Product`
  * `Applied Filters` should show `Package/Case` and `Resistance`

  Applied Filters
  * In the table, click the `Search Ascending` arrow under `Price` to show the lowest cost components
    * For this keyboard, there really aren't any components where using a more expensive part is worth getting

  Resistor
* Repeat this process for all the other components, or use the products I listed in the table

## Components From Other Sources

* I already owned the crystal oscillators, which is why I use through hole for them
  * [Amazon - uxcell 16.00 MHz crystal oscillator](https://smile.amazon.com/a14073000ux0239-Profile-Crystal-Oscillator-Replacements/dp/B00SWK2HCO)
* [Amazon - Brass M3 Screw and Standoff Kit](https://smile.amazon.com/Csdtylh-Male-Female-Standoff-Stainless-Assortment/dp/B06Y5TJXY1)

### Keyswitches

* I recommend ordering keyswitches from [Mechanicalkeyboards.com](https://mechanicalkeyboards.com/shop/index.php?l=product_list&c=107)
* **MAKE SURE THE SWITCHES YOU CHOOSE SAY PCB MOUNT**
  * I used my favorite switch, Kalih Speed Copper, which is plate mount
  * PCB mounted switches have two additional feet to help alignment
  * Plate mounted switches are very hard to align
  * Do not buy plate mounted switches

Plate Mount

PCB Mount

**WIP**

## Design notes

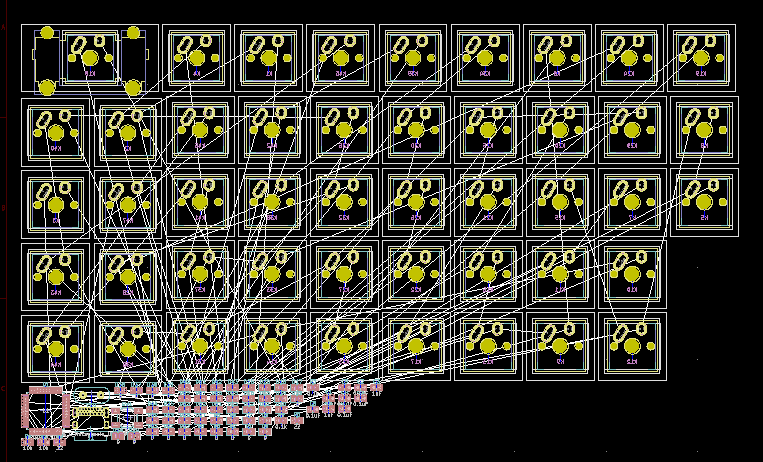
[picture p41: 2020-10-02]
images/update_pcb.PNG

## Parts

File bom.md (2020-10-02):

# Bill Of Materials

## Purchased

Item # | Store | Item | Unit Price | Units Purchased | Cost
------- |----------|------|------------|-----------------|----
1 | Digikey | USB C Receptacle | $1.37 | 3 | $4.11
2 | Digikey | Crystal | $0.36 | 5 | $1.80
3 | Digikey | Capacitor (22 pF) | $0.0364 | 50 | $1.82
4 | Digikey | Capacitor (1 $\mu$F) | $0.124 | 10 | $1.24
5 | Digikey | Capacitor (0.1 $\mu$F) | $0.04040 | 50 | $2.02
6 | Digikey | Resistor (22 $\Omega$) | $0.00750 | 100 | $0.75
7 | Digikey | Resistor (10 k$\Omega$) | $0.0180 | 10 | $0.18
8 | Digikey | Diode (1N4148) | $0.07080 | 100 | $7.08
9 | Digikey | Button | $0.59 | 3 | $1.77
10 | Digikey | $\mu$Controller | $4.08 | 2 | $8.16
11 | MechanicalKeyboards.com | Mechanical Keyboard Switches | $0.538 | 50 | $26.90
12 | JLCPCB | PCB (+Shipping) | $5.85 | 5 | $29.25
13 | Amazon | 360 Piece M3 Screw/Standoff Kit | $11.98 | 1 | $11.98
Total ||||| $85.08

## Per Keyboard

Item # | Item | Units | Cost |
-------|------|-------|------|
1 | USB C Receptacle | 1 | $1.37
2 | Crystal | 1 | $0.36
3 | Capacitor (22 pF) | 2 | $0.728
4 | Capacitor (1 $\mu$F) | 1 | $0.124
5 | Capacitor (0.1 $\mu$F) | 5 | $0.202
6 | Resistor (22 $\Omega$) | 2 | $0.015
7 | Resistor (10 k$\Omega$) | 2 | $0.36
7 | Diode (1N4148) | 47 | $3.33
8 | Button | 1 | $0.59
9 | $\mu$Controller | 1 | $4.08
10 | Mechanical Keyboard Switches | 47 | $25.29
11 | PCB | 1 | $5.85
12 | M3 Screw | 5 | $0.166
13 | M3 Standoff | 5 | $0.166
|| Total || $42.63

## Materials and Tools

* Soldering Iron
* Solder
* Solder Flux
* Helping Hands
* Tweezers
* Multimeter

## Outstanding

* Keycaps
* Plate for PCB
* Case

## Product Links

## Digikey Order 2
| Item # | Item | Price | Digikey Link | Data Sheet |
| --- | ---- | ---| ---| --- |
1 | USB C Connector | \$1.37 | [Link](https://www.digikey.com/product-detail/en/gct/USB4085-GF-A/2073-USB4085-GF-ACT-ND/9859733) | [Link](https://media.digikey.com/pdf/Data%20Sheets/GCT%20PDFs/Ionex_USB_Conn_Br.pdf)
2 | Capacitor (22pF) | \$0.043 | [Link](https://www.digikey.com/product-detail/en/w%C3%BCrth-elektronik/885012007012/732-7816-1-ND/5454443) | [Link](https://www.we-online.de/katalog/datasheet/885012007012.pdf)
3 | Capacitor (0.1 $\mu$F) | \$0.0216 | [Link](https://www.digikey.com/product-detail/en/samsung-electro-mechanics/CL21B104KACNNNC/1276-1099-1-ND/3889185) | [Link](https://media.digikey.com/pdf/Data%20Sheets/Samsung%20PDFs/CL21B104KACNNNC_Spec.pdf)
4 | Capacitor (1 $\mu$F) | \$0.055 | [Link](https://www.digikey.com/product-detail/en/samsung-electro-mechanics/CL21B105KOFNNNE/1276-1026-1-ND/3889112) | [Link](https://www.datasheets360.com/pdf/5320303544541785574)
5 | Diode | \$.02446 | [Link](https://www.digikey.com/product-detail/en/nexperia-usa-inc/BAS16GWJ/1727-7320-1-ND/7390571) | [Link](https://assets.nexperia.com/documents/data-sheet/BAS16GW.pdf)
6 | LED (Blue) | \$0.159 | [Link](https://www.digikey.com/product-detail/en/w%C3%BCrth-elektronik/150080BS75000/732-4982-1-ND/4489910) | [Link](https://www.we-online.de/katalog/datasheet/150080BS75000.pdf)
7 | Resistor (10 k$\Omega$) | $0.0071 | [Link](https://www.digikey.com/product-detail/en/stackpole-electronics-inc/RMCF0805JT10K0/RMCF0805JT10K0CT-ND/1942577) | [Link](https://www.seielect.com/catalog/sei-rmcf_rmcp.pdf)
8 | Resistor (22 $\Omega$) | $0.0071 | [Link](https://www.digikey.com/product-detail/en/stackpole-electronics-inc/RMCF0805JT22R0/RMCF0805JT22R0CT-ND/1942533) | [Link](https://www.seielect.com/catalog/sei-rmcf_rmcp.pdf)
9 | Resistor (5.1 k$\Omega$) | $0.0071 | [Link](https://www.digikey.com/product-detail/en/stackpole-electronics-inc/RMCF0805JT5K10/RMCF0805JT5K10CT-ND/1942571) | [Link](https://www.seielect.com/catalog/sei-rmcf_rmcp.pdf)
10 | Resistor (220 $\Omega$) | $0.0071 | [Link](https://www.digikey.com/product-detail/en/stackpole-electronics-inc/RMCF0805JT220R/RMCF0805JT220RCT-ND/1942544) | [Link](https://www.seielect.com/catalog/sei-packaging.pdf)
11 | Switch | $0.59 | [Link](https://www.digikey.com/product-detail/en/e-switch/TL3342F160QG-TR/EG2531CT-ND/379004) | [Link](https://sten-eswitch-13110800-production.s3.amazonaws.com/system/asset/product_line/data_sheet/165/TL3342.pdf)

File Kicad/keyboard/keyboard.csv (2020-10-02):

Reference | Quantity | Value | Footprint | Datasheet
C1 C2 | 2 | 22pF | Capacitor_SMD:C_0805_2012Metric | ~
C3 C4 C5 C6 C7 | 5 | 0.1uF | Capacitor_SMD:C_0805_2012Metric | ~
C8 | 1 | 1uF | Capacitor_SMD:C_0805_2012Metric | ~
D1 D2 D3 D5 D4 D6 D7 D9 D8 D10 D11 D12 D13 D14 D15 D17 D16 D18 D19 D21 D20 D22 D23 D24 D25 D26 D27 D29 D28 D30 D31 D33 D32 D34 D35 D36 D37 D38 D39 D41 D40 D42 D44 D43 D45 D46 D47 | 47 | D | keyboard_parts:D_SOD123_axial | ~
J1 | 1 | USB_C_Receptacle_USB2.0 | Type-C:USB_C_GCT_USB4085 | https://www.usb.org/sites/default/files/documents/usb_type-c.zip
K1 K2 K3 K4 K5 K6 K7 K8 K9 K10 K11 K12 K13 K14 K15 K16 K17 K18 K19 K20 K21 K22 K23 K25 K26 K27 K28 K29 K30 K31 K32 K33 K34 K35 K36 K37 K38 K39 K40 K41 K43 K44 K45 K46 K47 K24 | 46 | KEYSW | keebs:Mx_Alps_100
K42 | 1 | KEYSW | keebs:Mx_Alps_200
R1 R2 | 2 | 10k | Resistor_SMD:R_0805_2012Metric | ~
R3 R4 | 2 | 22 | Resistor_SMD:R_0805_2012Metric | ~
SW1 | 1 | SW_PUSH | Button_Switch_SMD:SW_SPST_TL3342
U1 | 1 | ATMEGA32U4 | Package_QFP:TQFP-44_10x10mm_P0.8mm
X1 | 1 | XTAL | keyboard_parts:XTAL_HC_49_TH

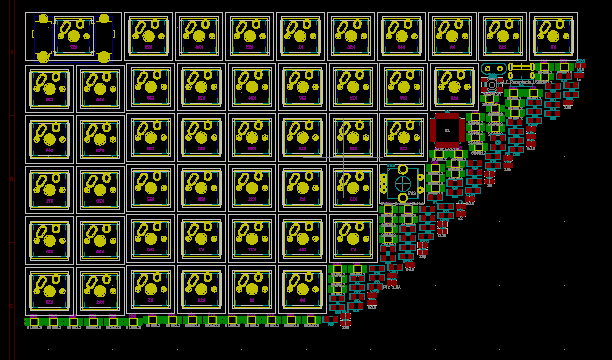
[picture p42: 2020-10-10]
Kicad/keyboard/rgb47/images/components_loaded.PNG

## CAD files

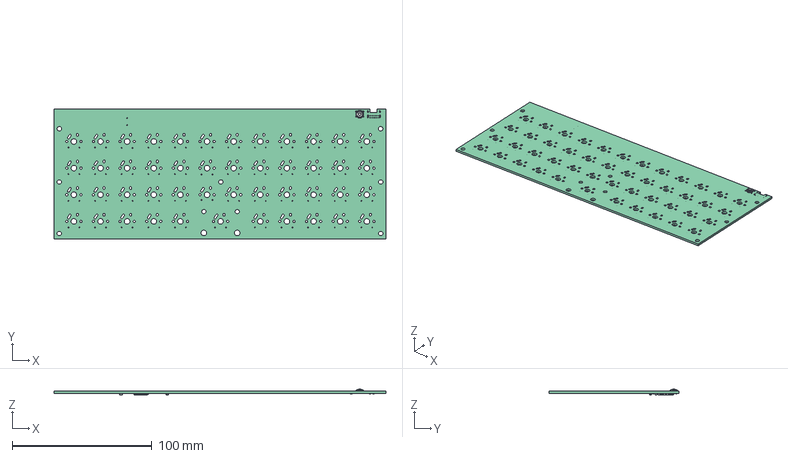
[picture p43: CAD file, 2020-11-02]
FreeCad/Model2_Case/Model2_Case.FCStd
237.5 x 92.7 x 4.39 mm
Pcb_5d60
D48_LED_0805_2012Metric_5F689551
R7_R_0805_2012Metric_5F6845C1
U1_TQFP_44_10x10mm_P08mm_5F58FB19
C3_C_0805_2012Metric_5F58EEA5
C1_C_0805_2012Metric_5F58EE83
C2_C_0805_2012Metric_5F58EE94
C4_C_0805_2012Metric_5F58EEB6
C5_C_0805_2012Metric_5F58EEC7
C6_C_0805_2012Metric_5F58EED8
C7_C_0805_2012Metric_5F58EEE9
C8_C_0805_2012Metric_5F58EEFA
R1_R_0805_2012Metric_5F58F99D
R2_R_0805_2012Metric_5F58F9AE
R3_R_0805_2012Metric_5F59C62D
R4_R_0805_2012Metric_5F58F9D0
SW1_SW_SPST_TL3342_5F58FA06
R5_R_0805_2012Metric_5F678B00
R6_R_0805_2012Metric_5F6787FB

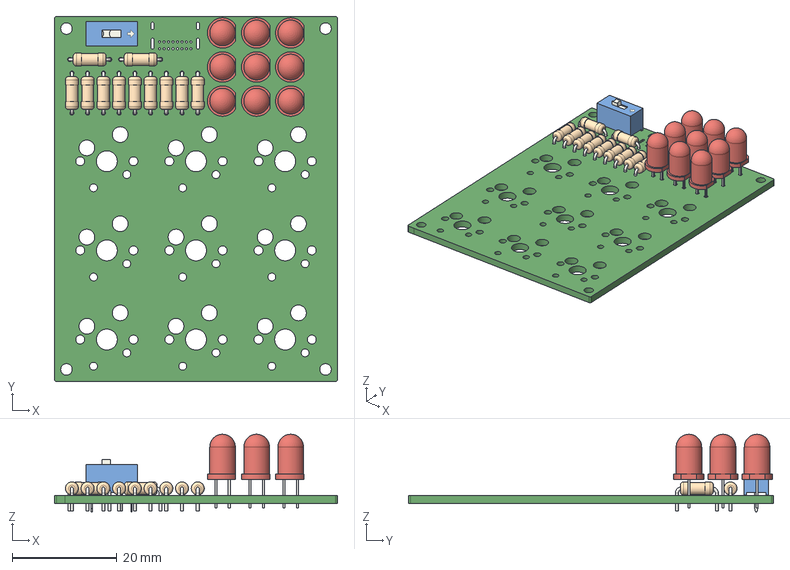
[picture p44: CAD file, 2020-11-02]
Kicad/switch_tester/rev_1_1_fab.step
54.0 x 69.6 x 14.8 mm

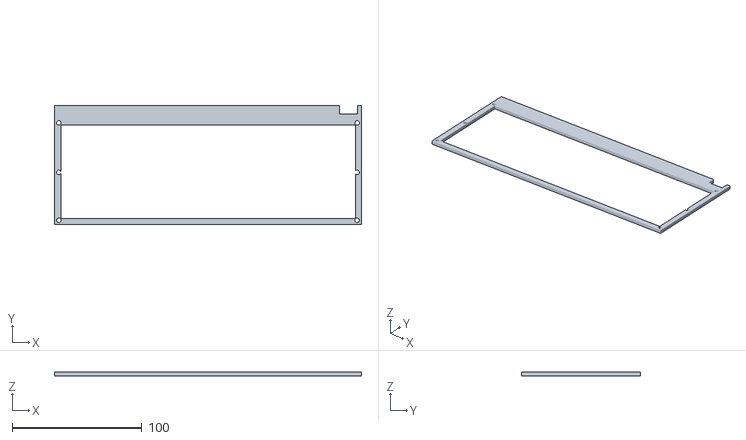
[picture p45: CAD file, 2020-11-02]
STL/Model2_Case_r1/plate.stl
236.3 x 91.7 x 3.00

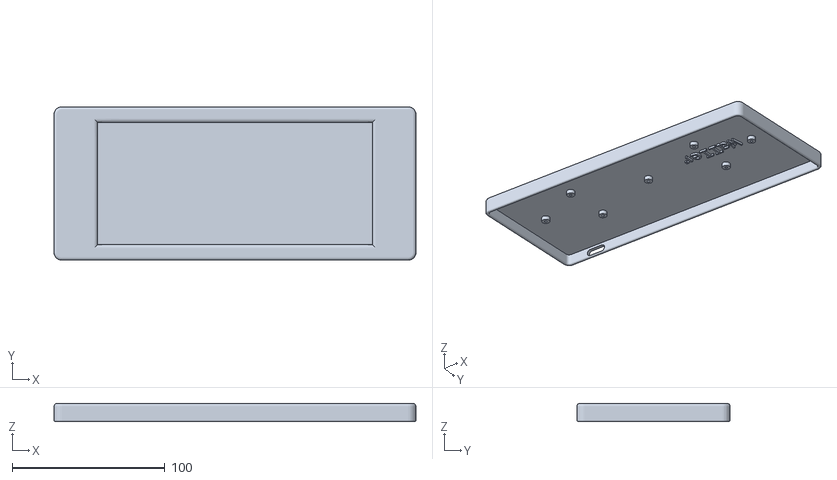
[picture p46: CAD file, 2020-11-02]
STL/rgb/print5.stl
237.4 x 100.6 x 12.0

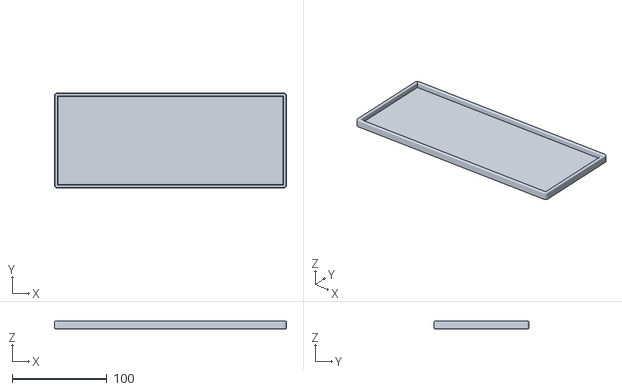
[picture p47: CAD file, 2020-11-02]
FreeCad/Model2_Case/CASE.stl
245.5 x 100.7 x 8.00

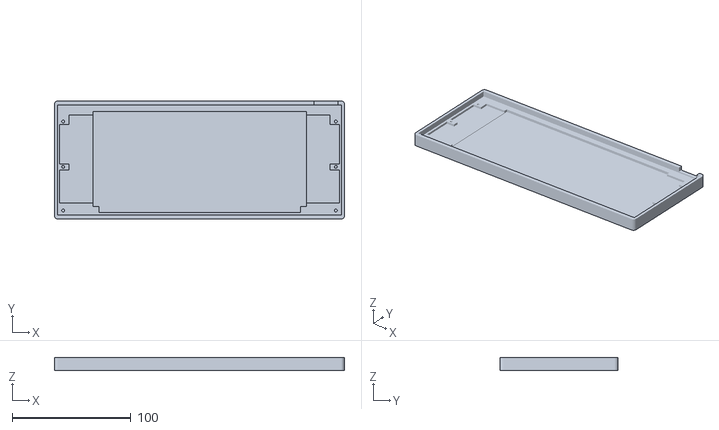
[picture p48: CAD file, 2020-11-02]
STL/Model2_Case_r1/case.stl
244.3 x 99.7 x 11.0

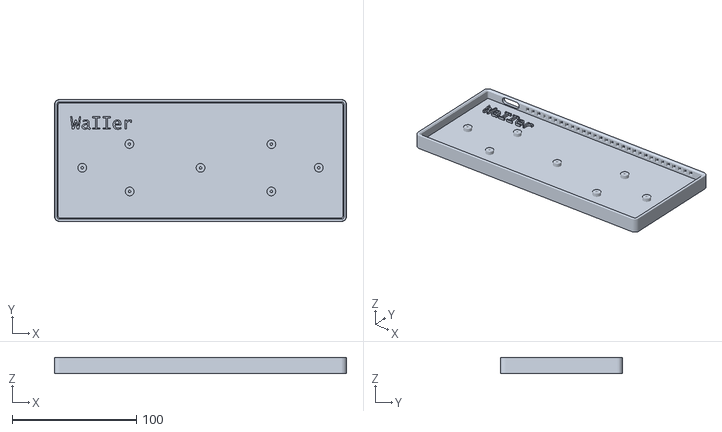
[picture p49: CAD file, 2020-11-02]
STL/rgb/print4.stl
235.4 x 98.6 x 13.0

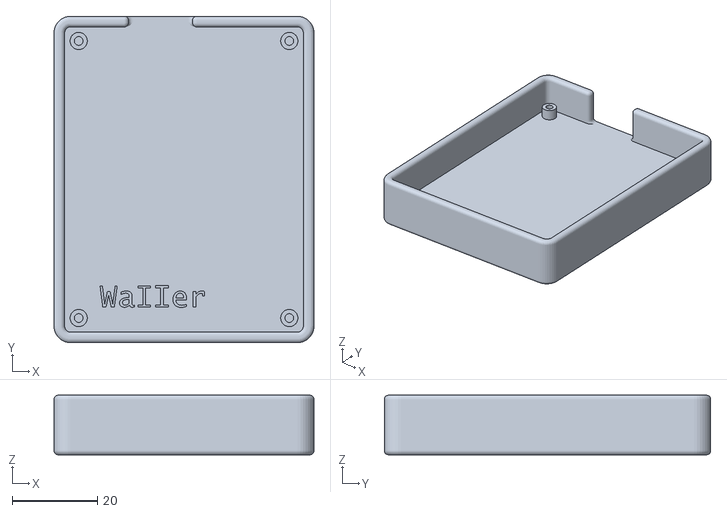
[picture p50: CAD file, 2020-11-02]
STL/switch_tester_1_1/prototype_2.stl
61.0 x 76.6 x 14.0

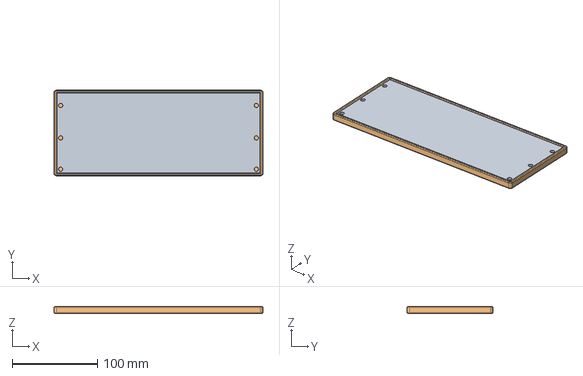
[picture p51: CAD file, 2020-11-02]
FreeCad/Model2_Case/Model2_Case2.FCStd
245.5 x 100.7 x 8.00 mm
Thickness001

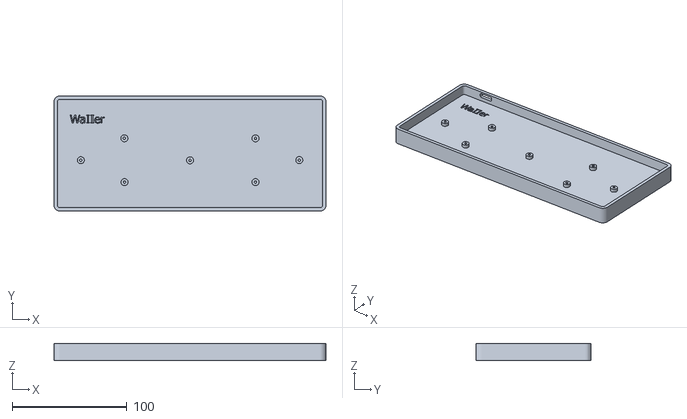
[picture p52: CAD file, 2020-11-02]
STL/rgb/print1.stl
237.4 x 100.6 x 15.0

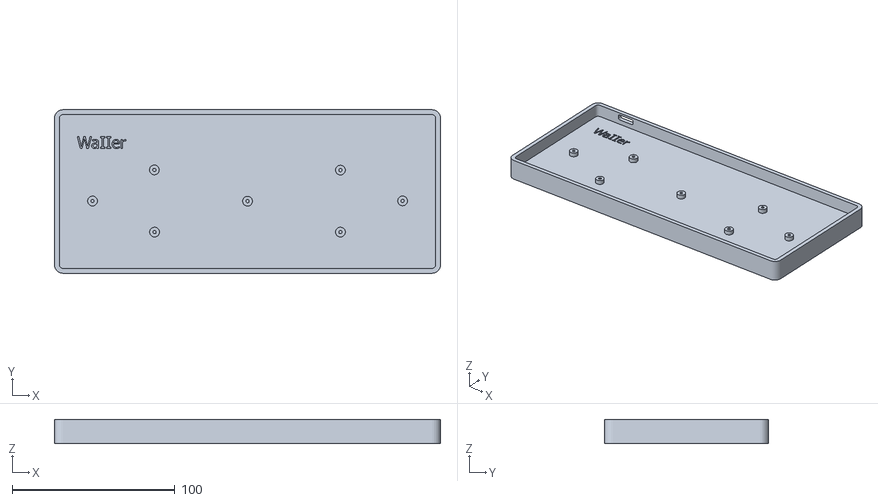
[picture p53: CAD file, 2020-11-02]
STL/rgb/print3.stl
237.4 x 100.6 x 15.0

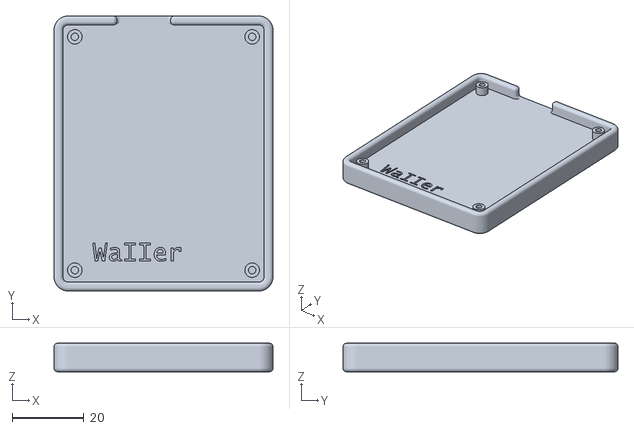
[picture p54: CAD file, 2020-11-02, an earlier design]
STL/switch_tester_1_1/prototype_1.stl
61.0 x 76.6 x 8.00

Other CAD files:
STL/rgb/print2.stl
STL/rgb/print6.stl
STL/rgb/print1_reduced.stl

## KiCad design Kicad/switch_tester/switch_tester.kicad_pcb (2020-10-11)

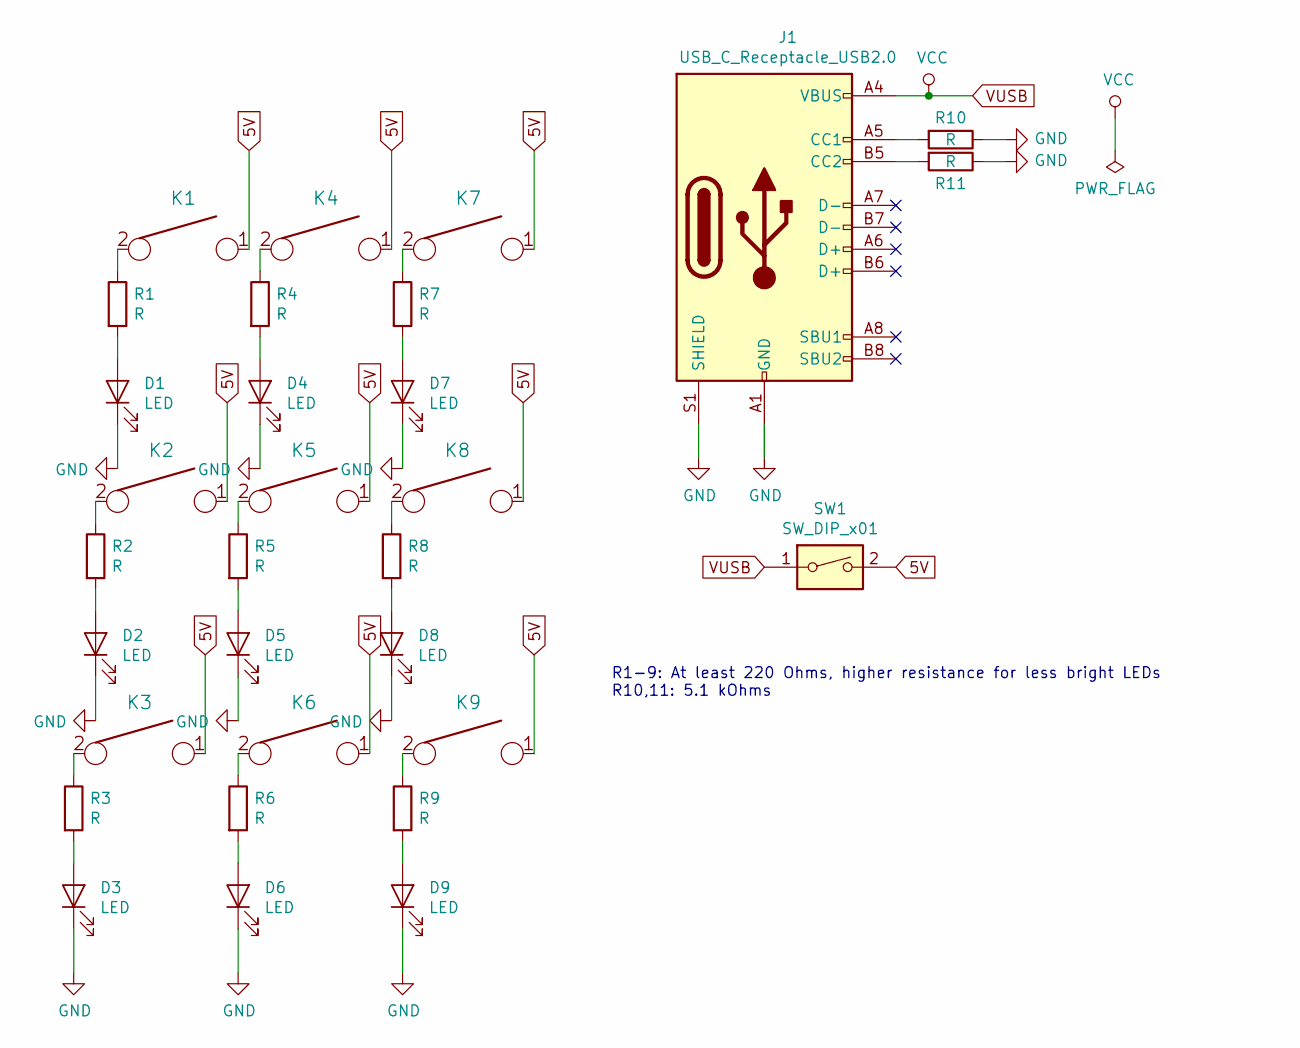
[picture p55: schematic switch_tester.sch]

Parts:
D1, D2, D3, D4, D5, D6, D7, D8, D9: LED; LED_D5.0mm
J1: USB_C_Receptacle_USB2.0; USB_C_GCT_USB4085
K1, K2, K3, K4, K5, K6, K7, K8, K9: KEYSW; Kailh_socket_MX_optional
R1, R2, R3, R4, R5, R6, R7, R8, R9, R10, R11: R; R_Axial_DIN0207_L6.3mm_D2.5mm_P7.62mm_Horizontal
SW1: SW_DIP_x01; SW_DIP_SPSTx01_Slide_9.78x4.72mm_W7.62mm_P2.54mm

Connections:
5V: K1.1, K2.1, K3.1, K4.1, K5.1, K6.1, K7.1, K8.1, K9.1, SW1.2
GND: D1.1 (K), D2.1 (K), D3.1 (K), D4.1 (K), D5.1 (K), D6.1 (K), D7.1 (K), D8.1 (K), D9.1 (K), J1.A1 (GND), J1.A12 (GND), J1.B1 (GND), J1.B12 (GND), J1.S1 (SHIELD), R10.1, R11.1
unnamed: D1.2 (A), R1.2
unnamed: D2.2 (A), R2.2
unnamed: D3.2 (A), R3.2
unnamed: D4.2 (A), R4.2
unnamed: D5.2 (A), R5.2
unnamed: D6.2 (A), R6.2
unnamed: D7.2 (A), R7.2
unnamed: D8.2 (A), R8.2
unnamed: D9.2 (A), R9.2
unnamed: J1.A5 (CC1), R10.2
unnamed: J1.B5 (CC2), R11.2
unnamed: K1.2, R1.1
unnamed: K2.2, R2.1
unnamed: K3.2, R3.1
unnamed: K4.2, R4.1
unnamed: K5.2, R5.1
unnamed: K6.2, R6.1
unnamed: K7.2, R7.1
unnamed: K8.2, R8.1
unnamed: K9.2, R9.1
VUSB: J1.A4 (VBUS), J1.A9 (VBUS), J1.B4 (VBUS), J1.B9 (VBUS), SW1.1

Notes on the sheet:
R1-9: At least 220 Ohms, higher resistance for less bright LEDs R10,11: 5.1 kOhms

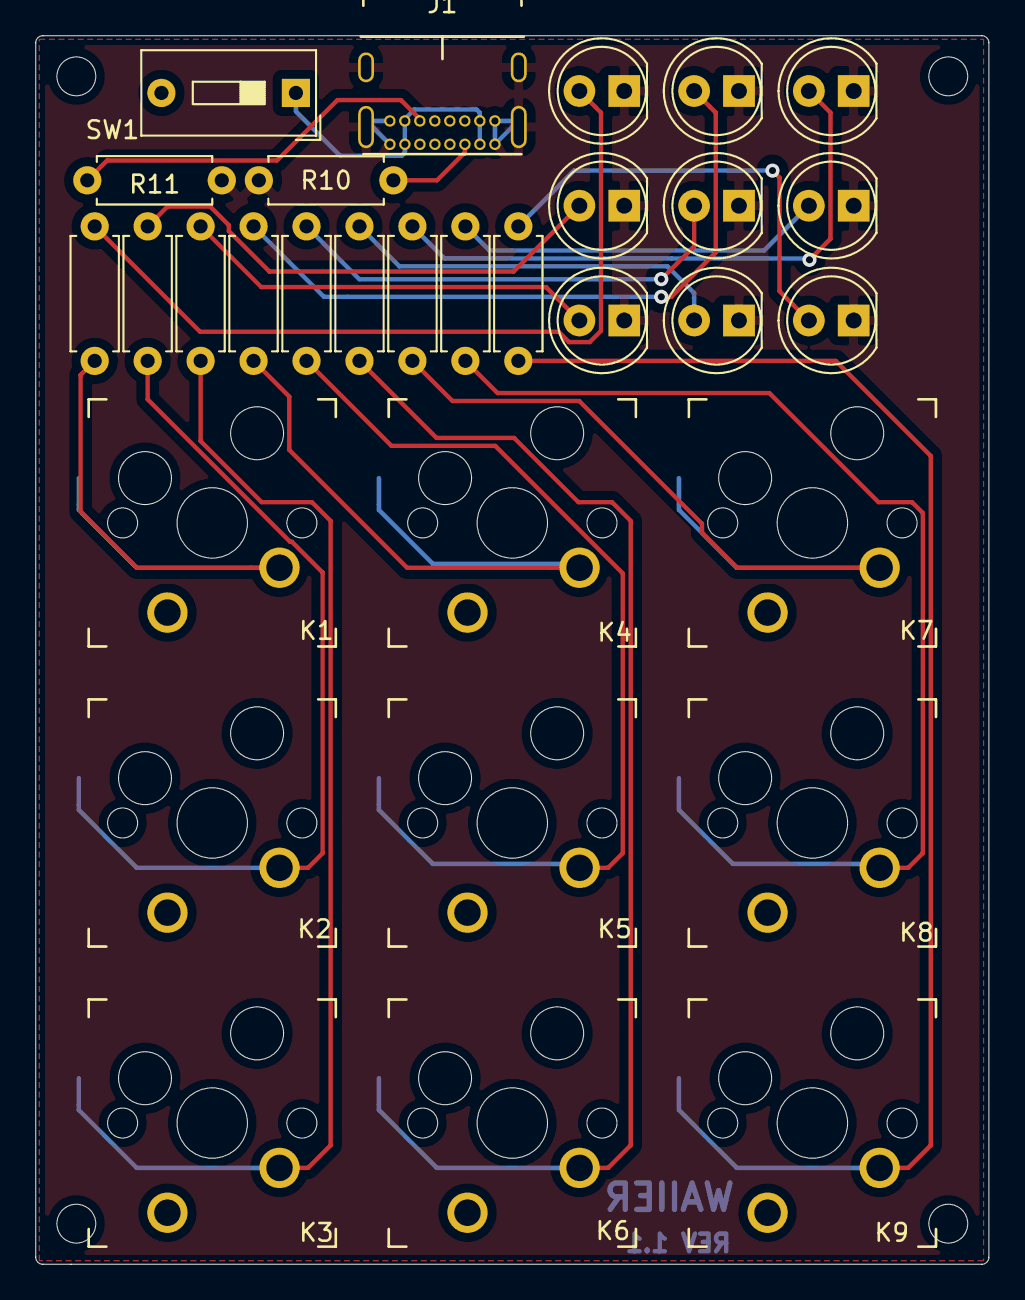
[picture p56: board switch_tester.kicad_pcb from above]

Board: 2 copper layers, 54.0 x 69.6 mm, 31 parts (0 on the bottom side), 23 nets.

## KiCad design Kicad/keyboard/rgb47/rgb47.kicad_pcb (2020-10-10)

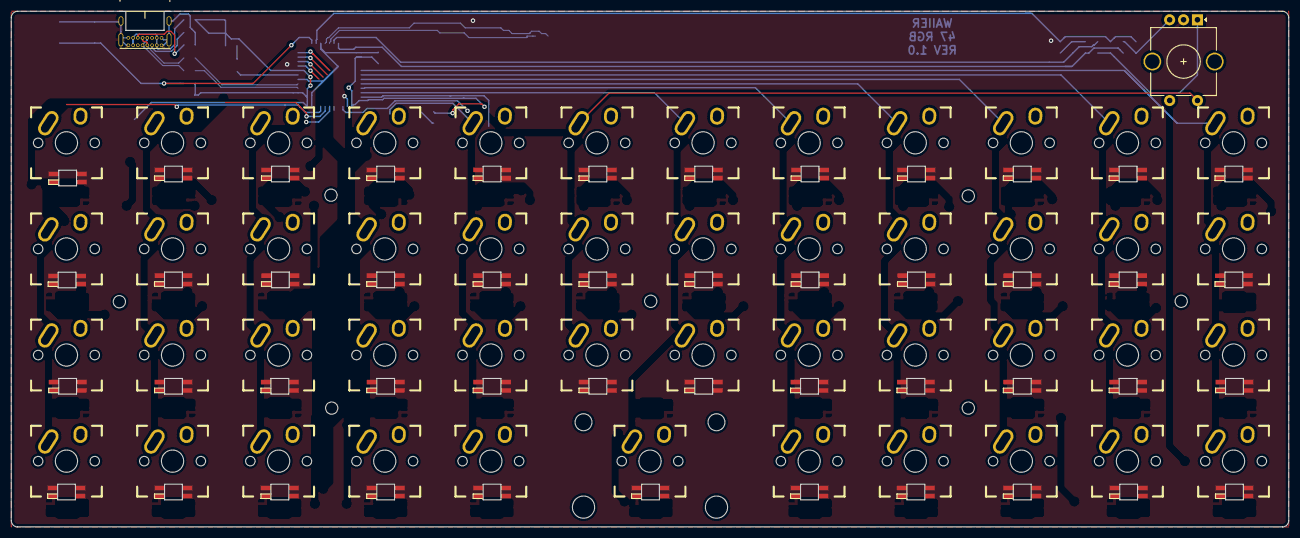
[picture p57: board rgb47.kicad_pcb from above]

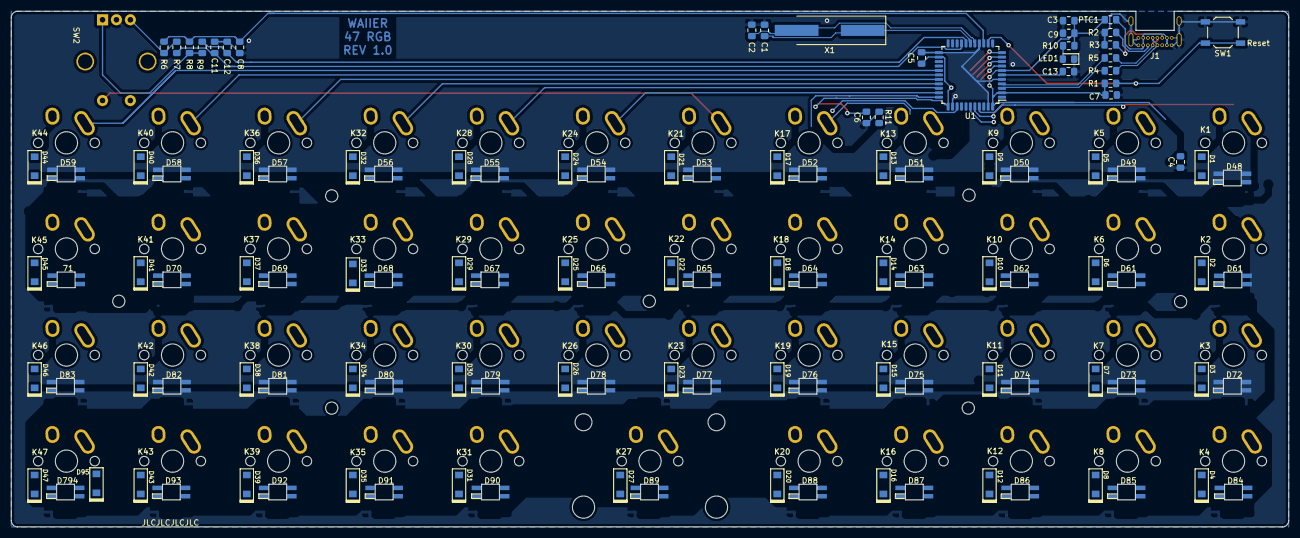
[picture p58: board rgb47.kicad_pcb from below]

Board: 2 copper layers, 229.4 x 92.6 mm, 172 parts (76 on the bottom side), 129 nets.

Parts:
71: SK6812; sk6812_mini_E_cuts
C1, C2: 22p; C_0805_2012Metric_Pad1.15x1.40mm_HandSolder
C3, C4, C5, C6, C7, C8, C11, C12: 0.1u; C_0805_2012Metric_Pad1.15x1.40mm_HandSolder
C9: 10u; C_0805_2012Metric_Pad1.15x1.40mm_HandSolder
C13: 1u; C_0805_2012Metric_Pad1.15x1.40mm_HandSolder
D1, D2, D3, D4, D5, D6, D7, D8, D9, D10, D11, D12, D13, D14, D15, D16, D17, D18, D19, D20, D21, D22, D23, D24, D25, D26, D27, D28, D29, D30, D31, D32, D33, D34, D35, D36, D37, D38, D39, D40, D41, D42, D43, D44, D45, D46, D47, D95: D; D_SOD123
D48, D49, D50, D51, D52, D53, D54, D55, D56, D57, D58, D59, D61, D61#2, D62, D63, D64, D65, D66, D67, D68, D69, D70, D72, D73, D74, D75, D76, D77, D78, D79, D80, D81, D82, D83, D84, D85, D86, D87, D88, D89, D90, D91, D92, D93, D794: SK6812; sk6812_mini_E_cuts
J1: USB_C_Receptacle_USB2.0; USB_C_GCT_USB4085
K1, K2, K3, K4, K5, K6, K7, K8, K9, K10, K11, K12, K13, K14, K15, K16, K17, K18, K19, K20, K21, K22, K23, K24, K25, K26, K28, K29, K30, K31, K32, K33, K34, K35, K36, K37, K38, K39, K40, K41, K42, K43, K44, K45, K46, K47: KEYSW; Mx_Alps_100
K27: KEYSW; Mx_Alps_200
LED1: LED; LED_0805_2012Metric_Pad1.15x1.40mm_HandSolder
PTC1: PTC 1.5A; Fuse_0805_2012Metric_Pad1.15x1.40mm_HandSolder
R1, R6, R7, R8, R9, R11: 10k; R_0805_2012Metric_Pad1.15x1.40mm_HandSolder
R2, R3: 5.1k; R_0805_2012Metric_Pad1.15x1.40mm_HandSolder
R4, R5: 22; R_0805_2012Metric_Pad1.15x1.40mm_HandSolder
R10: 220; R_0805_2012Metric_Pad1.15x1.40mm_HandSolder
SW1: SW_PUSH; SW_SPST_TL3342
SW2: Rotary_Encoder_Switch; RotaryEncoder_Alps_EC11E-Switch_Vertical_H20mm_CircularMoun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
U1: ATMEGA32U4; LQFP-44_10x10mm_P0.8mm
X1: XTAL; Crystal_SMD_HC49-SD_HandSoldering

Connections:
5V: 71.3, C3.2, C4.2, C5.2, C6.2, C7.2, C8.2, C9.2, D48.3, D49.3, D50.3, D51.3, D52.3, D53.3, D54.3, D55.3, D56.3, D57.3, D58.3, D59.3, D61.3, D61#2.3, D62.3, D63.3, D64.3, D65.3, D66.3, D67.3, D68.3, D69.3, D70.3, D72.3, D73.3, D74.3, D75.3, D76.3, D77.3, D78.3, D79.3, D80.3, D81.3, D82.3, D83.3, D84.3, D85.3, D86.3, D87.3, D88.3, D89.3, D90.3, D91.3, D92.3, D93.3, D794.1, PTC1.2, R1.1, R6.2, R8.2, R10.1, U1.2, U1.7, U1.14, U1.24, U1.34, U1.44
/COL0: K1.1, K2.1, K3.1, K4.1, U1.41
/COL1: K5.1, K6.1, K7.1, K8.1, U1.40
/COL2: K9.1, K10.1, K11.1, K12.1, U1.39
/COL3: K13.1, K14.1, K15.1, K16.1, U1.38
/COL4: K17.1, K18.1, K19.1, K20.1, U1.37
/COL5: K21.1, K22.1, K23.1, SW2.S2, U1.36
/COL6: K24.1, K25.1, K26.1, K27.1, U1.32
/COL7: K28.1, K29.1, K30.1, K31.1, U1.31
/COL8: K32.1, K33.1, K34.1, K35.1, U1.30
/COL9: K36.1, K37.1, K38.1, K39.1, U1.29
/COL10: K40.1, K41.1, K42.1, K43.1, U1.28
/COL11: K44.1, K45.1, K46.1, K47.1, U1.27
/D+: R5.1, U1.4
/D-: R4.1, U1.3
/ENCODER_A: R8.1, R9.2, SW2.A
/ENCODER_AOUT: C12.2, R9.1, U1.18
/ENCODER_B: R6.1, R7.2, SW2.B
/ENCODER_BOUT: C11.2, R7.1, U1.19
/ENCODER_S1: D95.2, SW2.S1
/RESET: R1.2, SW1.1, U1.13
/RGB: D48.2, U1.1
/ROW0: D1.1, D5.1, D9.1, D13.1, D17.1, D21.1, D24.1, D28.1, D32.1, D36.1, D40.1, D44.1, U1.8
/ROW1: D2.1, D6.1, D10.1, D14.1, D18.1, D22.1, D25.1, D29.1, D33.1, D37.1, D41.1, D45.1, U1.9
/ROW2: D3.1, D7.1, D11.1, D15.1, D19.1, D23.1, D26.1, D30.1, D34.1, D38.1, D42.1, D46.1, U1.10
/ROW3: D4.1, D8.1, D12.1, D16.1, D20.1, D27.1, D31.1, D35.1, D39.1, D43.1, D47.1, D95.1, U1.11
/XTAL_N: C2.2, U1.16, X1.2
/XTAL_P: C1.2, U1.17, X1.1
GND: 71.1, C1.1, C2.1, C3.1, C4.1, C5.1, C6.1, C7.1, C8.1, C9.1, C11.1, C12.1, C13.2, D48.1, D49.1, D50.1, D51.1, D52.1, D53.1, D54.1, D55.1, D56.1, D57.1, D58.1, D59.1, D61.1, D61#2.1, D62.1, D63.1, D64.1, D65.1, D66.1, D67.1, D68.1, D69.1, D70.1, D72.1, D73.1, D74.1, D75.1, D76.1, D77.1, D78.1, D79.1, D80.1, D81.1, D82.1, D83.1, D84.1, D85.1, D86.1, D87.1, D88.1, D89.1, D90.1, D91.1, D92.1, D93.1, D794.3, J1.A1, J1.A12, J1.B1, J1.B12, J1.S1, LED1.1, R2.1, R3.1, R11.1, SW1.2, SW2.C, U1.5, U1.15, U1.23, U1.35, U1.43
unnamed: C13.1, U1.6
unnamed: D1.2, K1.2
unnamed: D2.2, K2.2
unnamed: D3.2, K3.2
unnamed: D4.2, K4.2
unnamed: D5.2, K5.2
unnamed: D6.2, K6.2
unnamed: D7.2, K7.2
unnamed: D8.2, K8.2
unnamed: D9.2, K9.2
unnamed: D10.2, K10.2
unnamed: D11.2, K11.2
unnamed: D12.2, K12.2
unnamed: D13.2, K13.2
unnamed: D14.2, K14.2
unnamed: D15.2, K15.2
unnamed: D16.2, K16.2
unnamed: D17.2, K17.2
unnamed: D18.2, K18.2
unnamed: D19.2, K19.2
unnamed: D20.2, K20.2
unnamed: D21.2, K21.2
unnamed: D22.2, K22.2
unnamed: D23.2, K23.2
unnamed: D24.2, K24.2
unnamed: D25.2, K25.2
unnamed: D26.2, K26.2
unnamed: D27.2, K27.2
unnamed: D28.2, K28.2
unnamed: D29.2, K29.2
unnamed: D30.2, K30.2
unnamed: D31.2, K31.2
unnamed: D32.2, K32.2
unnamed: D33.2, K33.2
unnamed: D34.2, K34.2
unnamed: D35.2, K35.2
unnamed: D36.2, K36.2
unnamed: D37.2, K37.2
unnamed: D38.2, K38.2
unnamed: D39.2, K39.2
unnamed: D40.2, K40.2
unnamed: D41.2, K41.2
unnamed: D42.2, K42.2
unnamed: D43.2, K43.2
unnamed: D44.2, K44.2
unnamed: D45.2, K45.2
unnamed: D46.2, K46.2
unnamed: D47.2, K47.2
unnamed: D48.4, D49.2
unnamed: D49.4, D50.2
unnamed: D50.4, D93.2
unnamed: D51.2, D93.4
unnamed: D51.4, D52.2
unnamed: D52.4, D53.2
unnamed: D53.4, D54.2
unnamed: D54.4, D55.2
unnamed: D55.4, D56.2
unnamed: D56.4, D57.2
unnamed: D57.4, D58.2
unnamed: D58.4, D70.2
unnamed: D59.2, D61.4
unnamed: 71.2, D59.4
unnamed: D61.2, D61#2.4
unnamed: D61#2.2, D62.4
unnamed: D62.2, D63.4
unnamed: D63.2, D64.4
unnamed: D64.2, D65.4
unnamed: D65.2, D66.4
unnamed: D66.2, D67.4
unnamed: D67.2, D68.4
unnamed: D68.2, D69.4
unnamed: D69.2, D70.4
unnamed: 71.4, D72.2
unnamed: D72.4, D73.2
unnamed: D73.4, D74.2
unnamed: D74.4, D794.4
unnamed: D75.2, D794.2
unnamed: D75.4, D76.2
unnamed: D76.4, D77.2
unnamed: D77.4, D78.2
unnamed: D78.4, D79.2
unnamed: D79.4, D80.2
unnamed: D80.4, D81.2
unnamed: D82.2, D83.4
unnamed: D83.2, D84.4
unnamed: D84.2, D85.4
unnamed: D85.2, D86.4
unnamed: D86.2, D87.4
unnamed: D87.2, D88.4
unnamed: D88.2, D89.4
unnamed: D89.2, D90.4
unnamed: D90.2, D91.4
unnamed: D91.2, D92.4
unnamed: J1.A5, R2.2
unnamed: J1.A6, J1.B6, R5.2
unnamed: J1.A7, J1.B7, R4.2
unnamed: J1.B5, R3.2
unnamed: LED1.2, R10.2
unnamed: R11.2, U1.33
VCC: J1.A4, J1.A9, J1.B4, J1.B9, PTC1.1

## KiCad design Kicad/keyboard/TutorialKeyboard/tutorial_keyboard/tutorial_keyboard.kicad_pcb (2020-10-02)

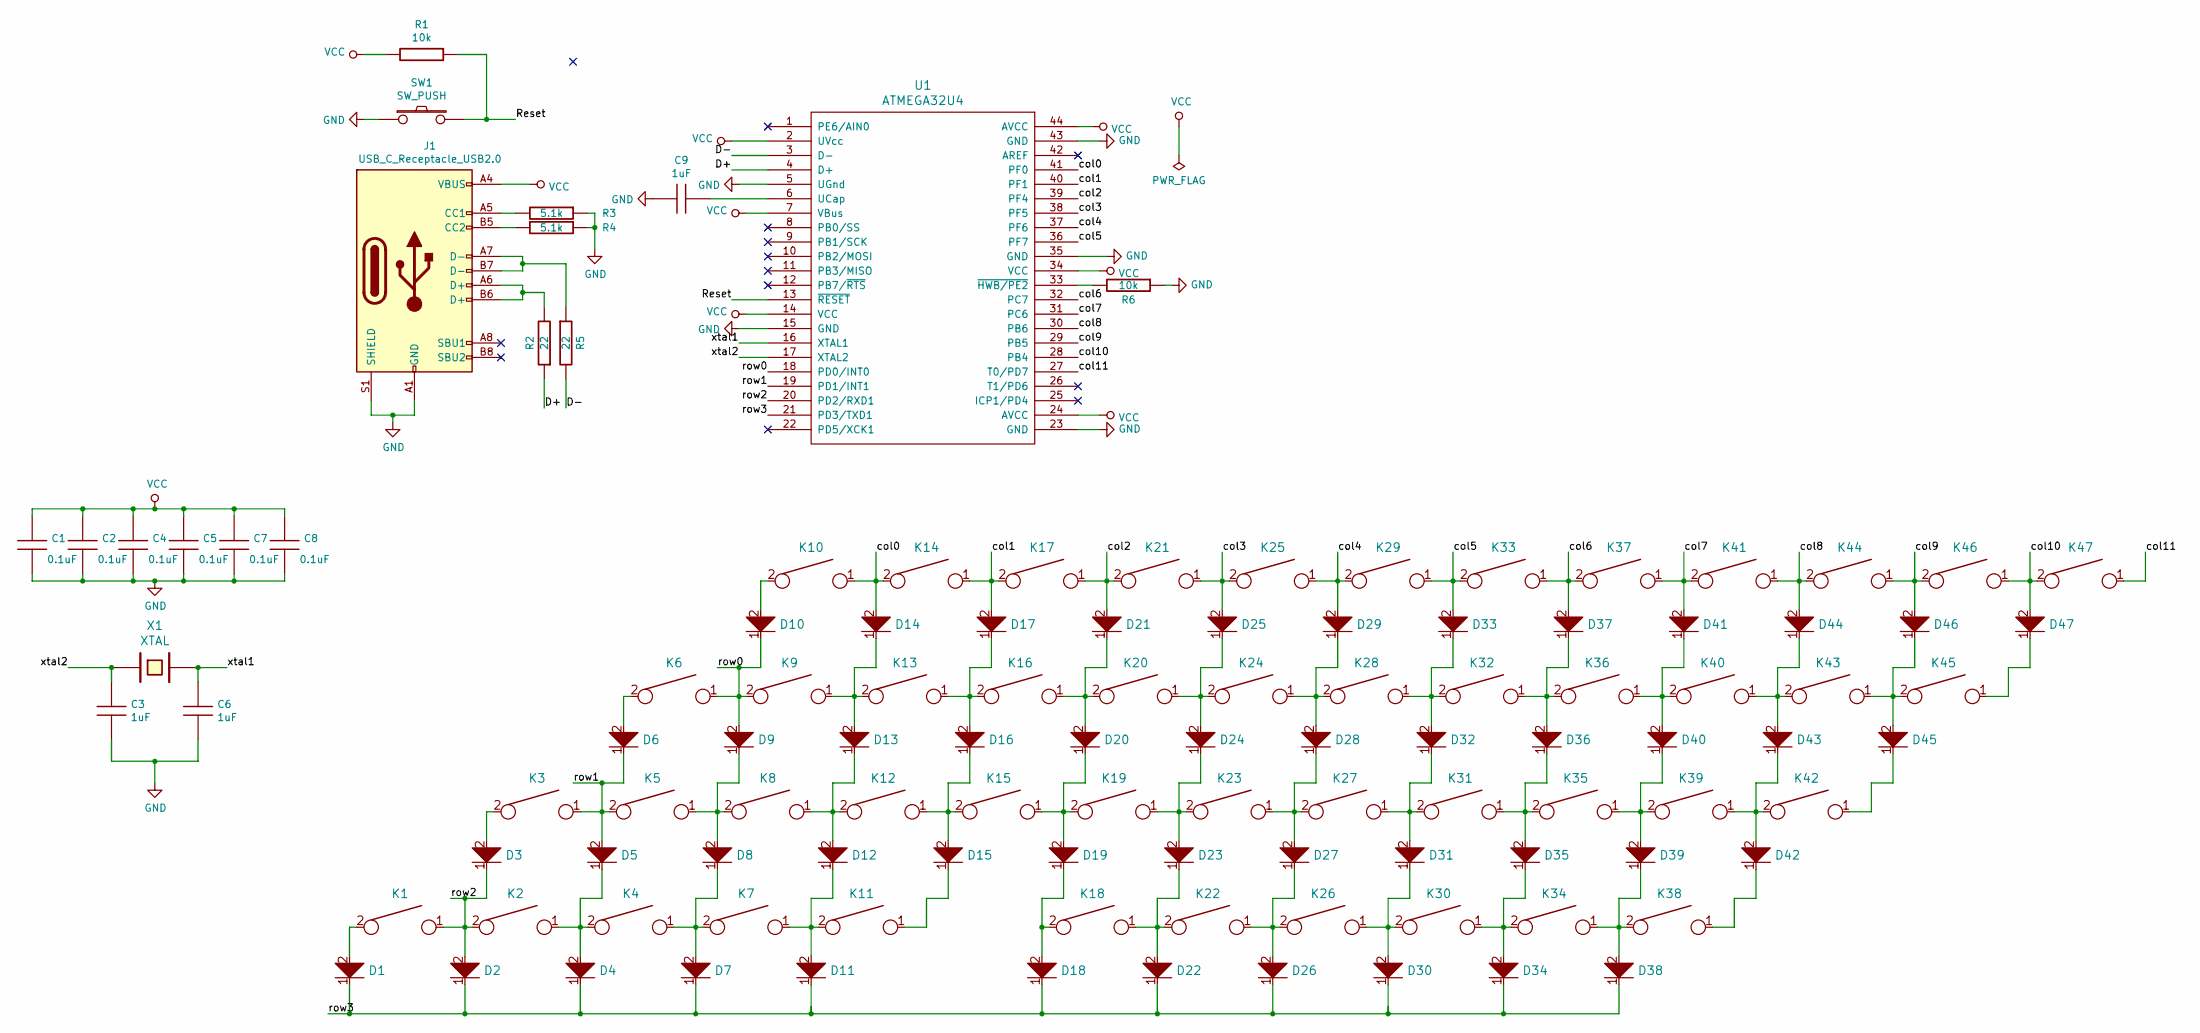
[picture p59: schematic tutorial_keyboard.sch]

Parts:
C1, C2, C4, C5, C7, C8: 0.1uF; C_0805_2012Metric
C3, C6, C9: 1uF; C_0805_2012Metric
D1, D2, D3, D4, D5, D6, D7, D8, D9, D10, D11, D12, D13, D14, D15, D16, D17, D18, D19, D20, D21, D22, D23, D24, D25, D26, D27, D28, D29, D30, D31, D32, D33, D34, D35, D36, D37, D38, D39, D40, D41, D42, D43, D44, D45, D46, D47: D; D_0805_2012Metric
J1: USB_C_Receptacle_USB2.0; USB_C_GCT_USB4085
K1, K2, K3, K4, K5, K6, K7, K8, K9, K10, K11, K12, K13, K14, K15, K16, K17, K19, K20, K21, K22, K23, K24, K25, K26, K27, K28, K29, K30, K31, K32, K33, K34, K35, K36, K37, K38, K39, K40, K41, K42, K43, K44, K45, K46, K47: KEYSW; Mx_Alps_100
K18: KEYSW; Mx_Alps_200
R1, R6: 10k; R_0805_2012Metric
R2, R5: 22; R_0805_2012Metric
R3, R4: 5.1k; R_0805_2012Metric
SW1: SW_PUSH; SW_SPST_TL3342
U1: ATMEGA32U4; LQFP-44_10x10mm_P0.8mm
X1: XTAL; XTAL_HC_49_TH

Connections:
/D+: R2.1, U1.4 (D+)
/D-: R5.2, U1.3 (D-)
/Reset: R1.1, SW1.2, U1.13 (~RESET)
/col0: D14.2, K10.1, K14.2, U1.41 (PF0)
/col1: D17.2, K14.1, K17.2, U1.40 (PF1)
/col2: D21.2, K17.1, K21.2, U1.39 (PF4)
/col3: D25.2, K21.1, K25.2, U1.38 (PF5)
/col4: D29.2, K25.1, K29.2, U1.37 (PF6)
/col5: D33.2, K29.1, K33.2, U1.36 (PF7)
/col6: D37.2, K33.1, K37.2, U1.32 (PC7)
/col7: D41.2, K37.1, K41.2, U1.31 (PC6)
/col8: D44.2, K41.1, K44.2, U1.30 (PB6)
/col9: D46.2, K44.1, K46.2, U1.29 (PB5)
/col10: D47.2, K46.1, K47.2, U1.28 (PB4)
/col11: K47.1, U1.27 (T0/PD7)
/row0: D9.2, D10.1, K6.1, K9.2, U1.18 (PD0/INT0)
/row1: D5.2, D6.1, K3.1, K5.2, U1.19 (PD1/INT1)
/row2: D2.2, D3.1, K1.1, K2.2, U1.20 (PD2/RXD1)
/row3: D1.1, D2.1, D4.1, D7.1, D11.1, D18.1, D22.1, D26.1, D30.1, D34.1, D38.1, U1.21 (PD3/TXD1)
/xtal1: C6.2, U1.16 (XTAL1), X1.2
/xtal2: C3.2, U1.17 (XTAL2), X1.1
GND: C1.1, C2.1, C3.1, C4.1, C5.1, C6.1, C7.1, C8.1, C9.2, J1.A1 (GND), J1.A12 (GND), J1.B1 (GND), J1.B12 (GND), J1.S1 (SHIELD), R3.1, R4.1, R6.1, SW1.1, U1.5 (UGnd), U1.15 (GND), U1.23 (GND), U1.35 (GND), U1.43 (GND)
unnamed: C9.1, U1.6 (UCap)
unnamed: D1.2, K1.2
unnamed: D3.2, K3.2
unnamed: D4.2, D5.1, K2.1, K4.2
unnamed: D6.2, K6.2
unnamed: D7.2, D8.1, K4.1, K7.2
unnamed: D8.2, D9.1, K5.1, K8.2
unnamed: D10.2, K10.2
unnamed: D11.2, D12.1, K7.1, K11.2
unnamed: D12.2, D13.1, K8.1, K12.2
unnamed: D13.2, D14.1, K9.1, K13.2
unnamed: D15.1, K11.1
unnamed: D15.2, D16.1, K12.1, K15.2
unnamed: D16.2, D17.1, K13.1, K16.2
unnamed: D18.2, D19.1, K18.2
unnamed: D19.2, D20.1, K15.1, K19.2
unnamed: D20.2, D21.1, K16.1, K20.2
unnamed: D22.2, D23.1, K18.1, K22.2
unnamed: D23.2, D24.1, K19.1, K23.2
unnamed: D24.2, D25.1, K20.1, K24.2
unnamed: D26.2, D27.1, K22.1, K26.2
unnamed: D27.2, D28.1, K23.1, K27.2
unnamed: D28.2, D29.1, K24.1, K28.2
unnamed: D30.2, D31.1, K26.1, K30.2
unnamed: D31.2, D32.1, K27.1, K31.2
unnamed: D32.2, D33.1, K28.1, K32.2
unnamed: D34.2, D35.1, K30.1, K34.2
unnamed: D35.2, D36.1, K31.1, K35.2
unnamed: D36.2, D37.1, K32.1, K36.2
unnamed: D38.2, D39.1, K34.1, K38.2
unnamed: D39.2, D40.1, K35.1, K39.2
unnamed: D40.2, D41.1, K36.1, K40.2
unnamed: D42.1, K38.1
unnamed: D42.2, D43.1, K39.1, K42.2
unnamed: D43.2, D44.1, K40.1, K43.2
unnamed: D45.1, K42.1
unnamed: D45.2, D46.1, K43.1, K45.2
unnamed: D47.1, K45.1
unnamed: J1.A5 (CC1), R3.2
unnamed: J1.A6 (D+), J1.B6 (D+), R2.2
unnamed: J1.A7 (D-), J1.B7 (D-), R5.1
unnamed: J1.B5 (CC2), R4.2
unnamed: R6.2, U1.33 (~HWB/PE2)
VCC: C1.2, C2.2, C4.2, C5.2, C7.2, C8.2, J1.A4 (VBUS), J1.A9 (VBUS), J1.B4 (VBUS), J1.B9 (VBUS), R1.2, U1.2 (UVcc), U1.7 (VBus), U1.14 (VCC), U1.24 (AVCC), U1.34 (VCC), U1.44 (AVCC)

Board: 2 copper layers, 113 parts (0 on the bottom side), 66 nets, no tracks yet.

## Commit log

2020-10-02 up to routing section
    [tutorial_keyboard.kicad_pcb, tutorial_keyboard.sch]
2020-10-03 pcb instructions finished
    [keyboard-B_Cu.gbr, keyboard-B_Mask.gbr, keyboard-B_Paste.gbr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]
2020-10-10 rgb47 added
    [all_connected.kicad_pcb, backup_before_changing rgb_footprint.kicad_pcb, backup_before_update.kicad_pcb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]
2020-10-11 switch testers
    [rev1_1.kicad_pcb, rev_1_1_fab.kicad_pcb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]
2020-11-02 long overdue update
    [CASE.stl, Model2_Case.FCStd, Model2_Case2.FCStd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]
